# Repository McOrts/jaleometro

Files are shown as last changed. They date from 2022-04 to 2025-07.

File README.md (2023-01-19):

#   Sensor remoto y autónomo de ruido ambiental 
Este dispositivo se ha diseñado para monitorizar el ruido ambiental de forma indefinida utilizando energía solar. 

Por otra parte se van a utilizar comunicaciones de largo alcance tipo LPWAN (Low Power Wide Area Networks). En este caso será una modulación **LoRa** (Long Range) que además es muy eficientes en el consumo de energía. La tecnología LoRa y la capa de red abierta LoRaWAN son los protagonistas del despliegue del IoT.

## Material utilizado
- Hemos utilizado la [placa Heltec HTCC-AB01](https://es.aliexpress.com/item/1005001288501966.html) para la banda ISM europea de 868MHz que tiene las siguientes características:
  - Compatible con Arduino, por tanto compatible en Windows, Mac OS y Linux
  - Configurable a través de comandos AT
  - Chip CP2102 de puerto serie a USB integrado
  - Basada en ASR605x (ASR6501, ASR6502) , esos chips ya están integrados el PSoC ®  4000 serie MCU (ARM® cortex® M0 + Core) y SX1262;
  - Soporte de la especificación LoRaWAN 1.0.2
  - Diseño de energía ultra bajo, solo 3.5uA en Deep Sleep. Para este tipo de proyecto, el consumo son muy importantes y aquí tenemos es tabla que ayudará a dimensionar la batería y el panel solar:
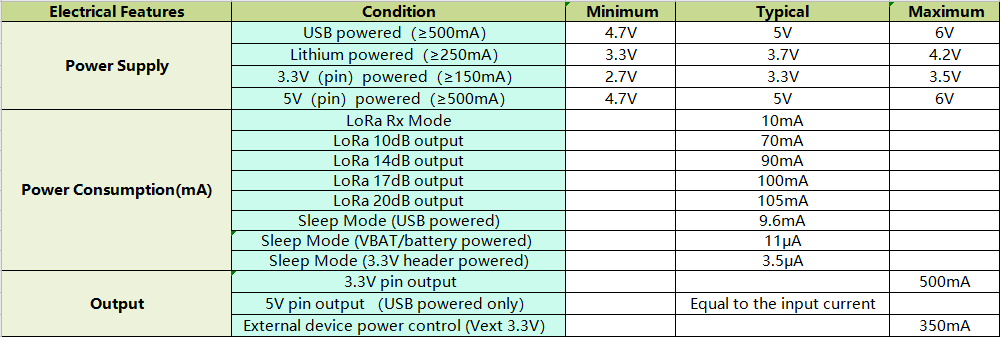
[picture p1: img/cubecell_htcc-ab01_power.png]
Consumos
   
  - Sistema de gestión de energía solar incluido, se puede conectar directamente con un panel solar de 5-7 V
  - Conector SH1.25-2 para baterías incluido, sistema de administración de batería integrado (administración de carga y descarga, protección de sobrecarga, detección de energía de la batería, conmutación automática de energía de batería / USB)
  - Interfaz micro USB con protección ESD (Electrostatic Discharge), protección contra cortocircuitos, blindaje RF y otras medidas de protección
  - Buena correspondencia de impedancia y larga distancia de comunicación
  - Certificación CE y FCC

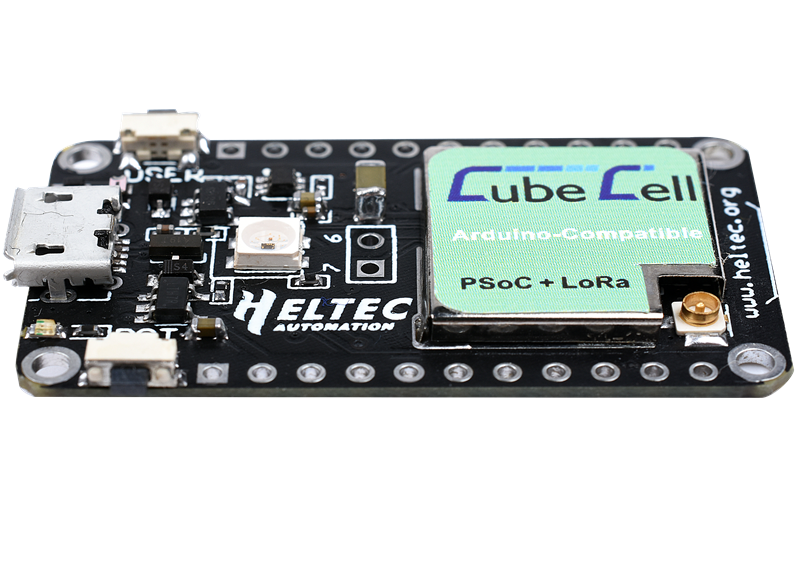
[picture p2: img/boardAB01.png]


Podremos encontrar toda la documentación de esta placa en: [Documentos y ficheros](https://resource.heltec.cn/download/CubeCell), [FAQs](https://github.com/HelTecAutomation/HeltecDocs/blob/master/en/source/cubecell/frequently_asked_questions.md) 

- [Batería de polímero de litio de 3,7V y conector JST SH1.0 de 1,0mm y dos pines](https://es.aliexpress.com/item/4000288987647.html)

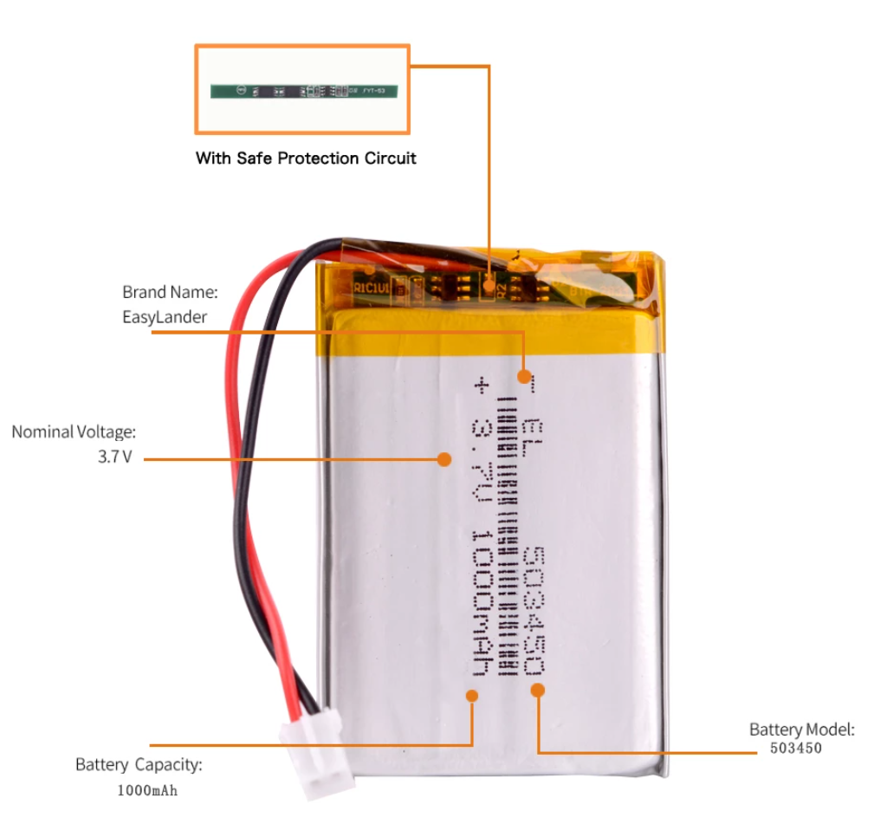
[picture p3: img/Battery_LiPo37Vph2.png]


- [Panel solar de 6V](https://es.aliexpress.com/item/4001128543657.html)

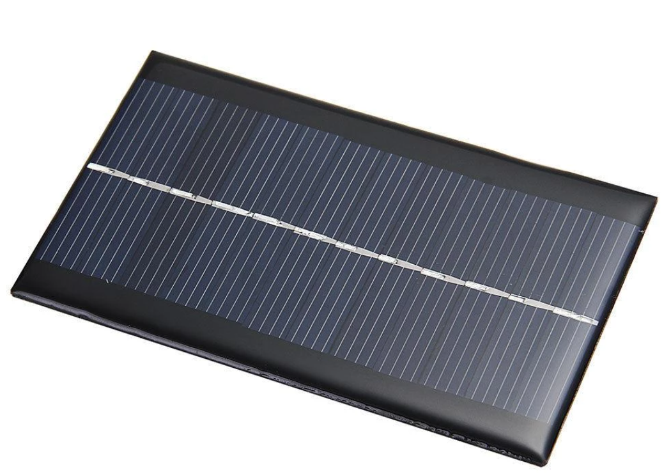
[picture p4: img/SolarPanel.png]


- [SparkFun Sound Detector](https://www.sparkfun.com/products/14262)

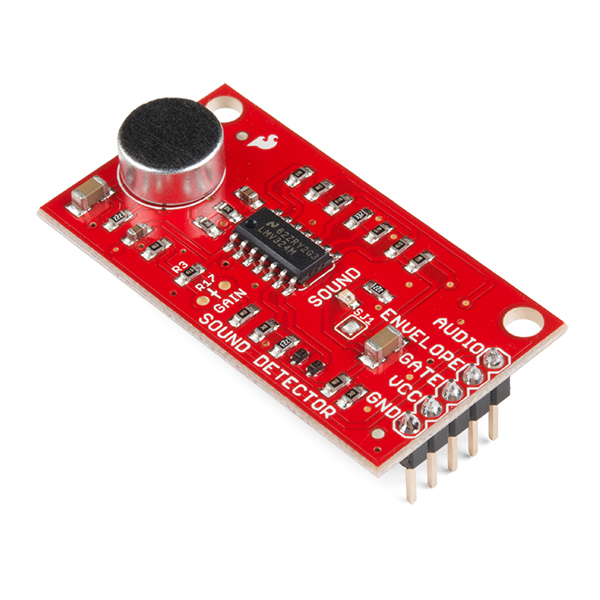
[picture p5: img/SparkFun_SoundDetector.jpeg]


- [Carcasa hermética IP66](https://es.aliexpress.com/item/33060319519.html)

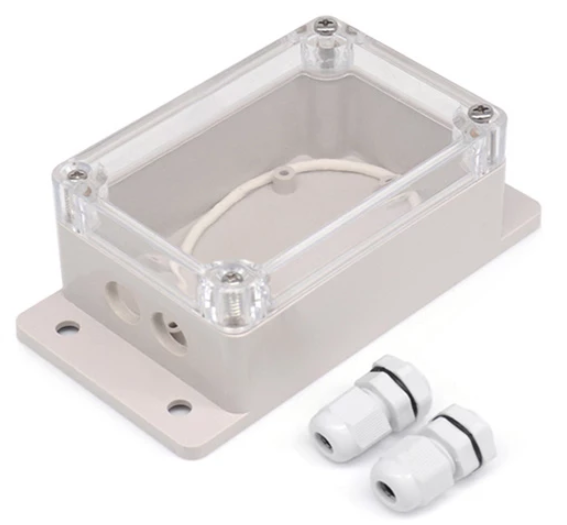
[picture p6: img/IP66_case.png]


Por otra parte también se necesitarán otros componentes no electrónicos como cables, mini-protoboard... lo que conforma este kit:

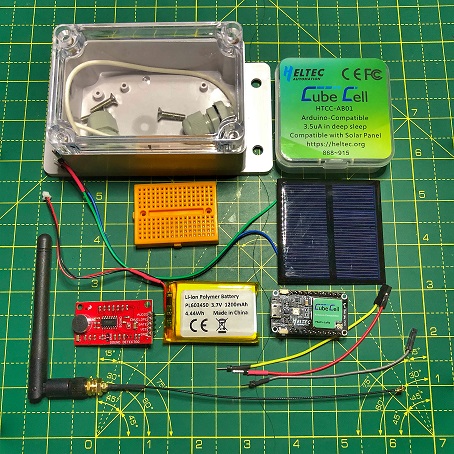
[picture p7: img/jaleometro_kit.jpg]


## Conexionado

Del microcontrolador CubeCell solo vamos a utilizar el pin 2 que corresponde al único conversor analógico/digital de la placa. Internamente es el mismo que utiliza para ver el estado de carga de la batería. Por lo que perderemos esta función.  

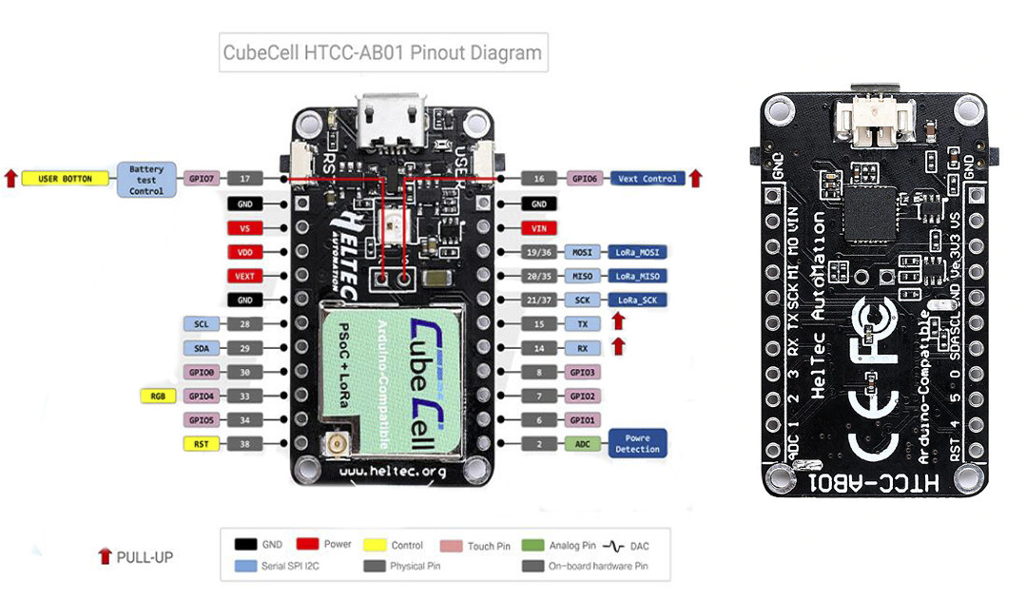
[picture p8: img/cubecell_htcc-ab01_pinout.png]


Otro detalle a tener en cuenta respecto a la alimentación del sensor de sonido, es que aunque sería recomendable utilizar una tensión de 5V que suministraría la placa por el pin VIN. Este solo tiene tensión cuando se alimenta por USB. Por lo que tendremos que utilizar el pin VDD que suministra 3.3 en la configuración de batería y son suficientes para que el sensor funciones correctamente.

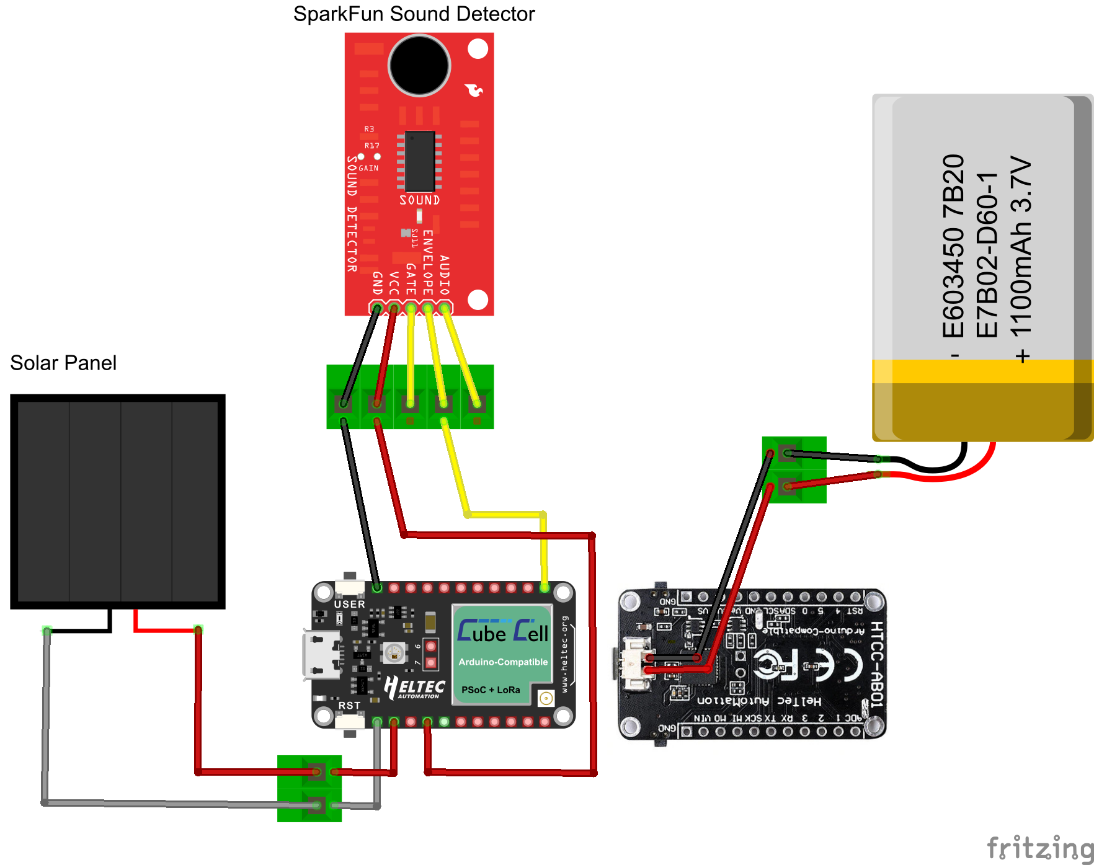
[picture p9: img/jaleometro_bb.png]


### Tuneo del sensor de Sparkfun
Las pruebas realizadas con la v0 revelaron falta de sensibilidad. El sensor permite esta ajuste por hardware soldando una resistencia en este punto:

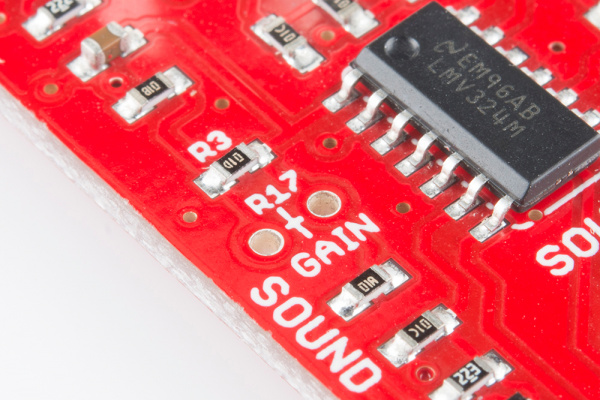
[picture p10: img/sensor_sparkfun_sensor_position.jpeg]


Los valores posibles están en esta tabla:



Y finalmente en nuestro caso elegimos la de 1M para obtener una ganancia de 60 dB:

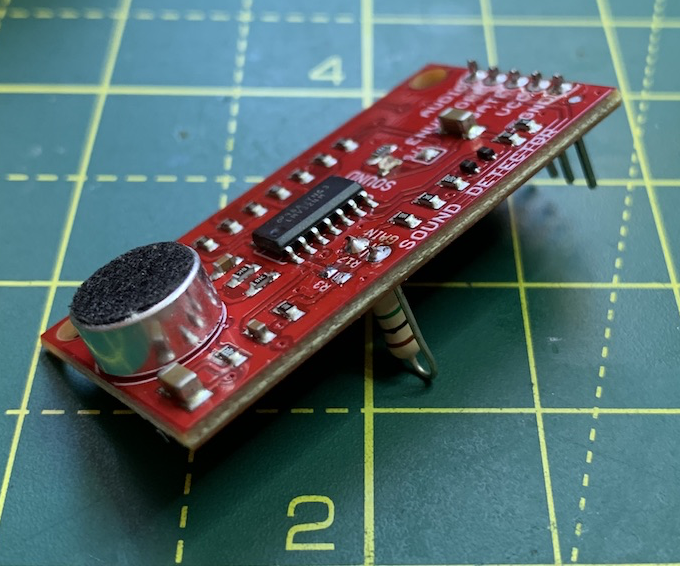
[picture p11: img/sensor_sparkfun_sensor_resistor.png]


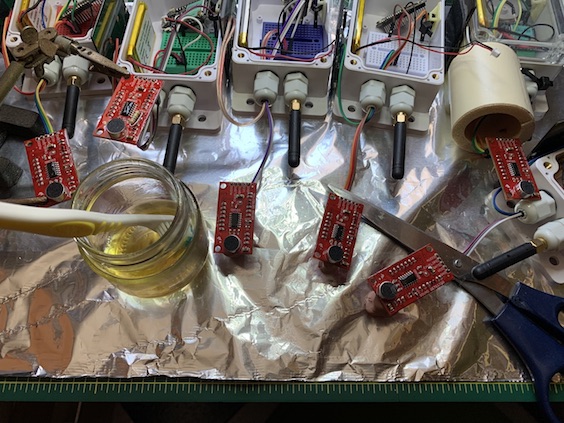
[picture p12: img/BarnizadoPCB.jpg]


Debido a que el sensor estará fuera de la caja estanca. Aunque protegido por material plástico. Requiere de una protección especial a fin de retardar todo lo posible la oxidación de sus componentes. Hay muchas soluciones, pero hemos elegido la más artesanal usando resina colofonia disuelta al 40% en alcohol isopropílico. La solución se puede aplicar con pincel y el tiempo de secado es de unas 24 horas.

## Configuración IDE Arduino
Lo para poder programar adecuadamente el dispositivo tendremos que configurar el entorno de programación de Arduino con las configuraciones de hardware y librerías de esta placa.
1. Añadir la URL https://github.com/HelTecAutomation/CubeCell-Arduino/releases/download/V1.5.0/package_CubeCell_index.json a Preferences->Settings->Additional boards:
2. Añadir la librería de CayenneLPP. **Importante: versión 1.1.0**:

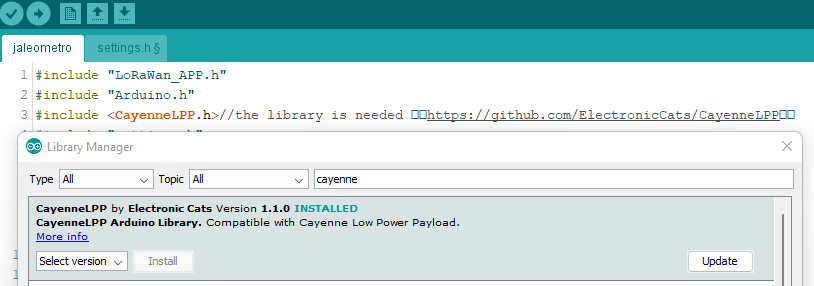
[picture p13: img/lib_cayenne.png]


3. Si aparece un aviso de instalar otras librerias con dependencias. Seleccionar opción de instalar todas:

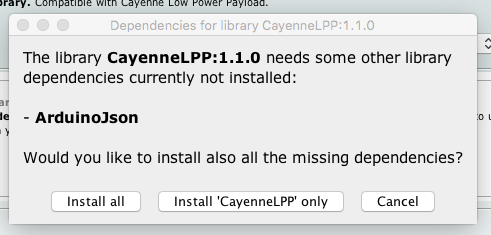
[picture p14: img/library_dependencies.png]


4. Seleccionar la tarjeta CubeCell HTCC-AB01 y configurar todos sus parámetros así:

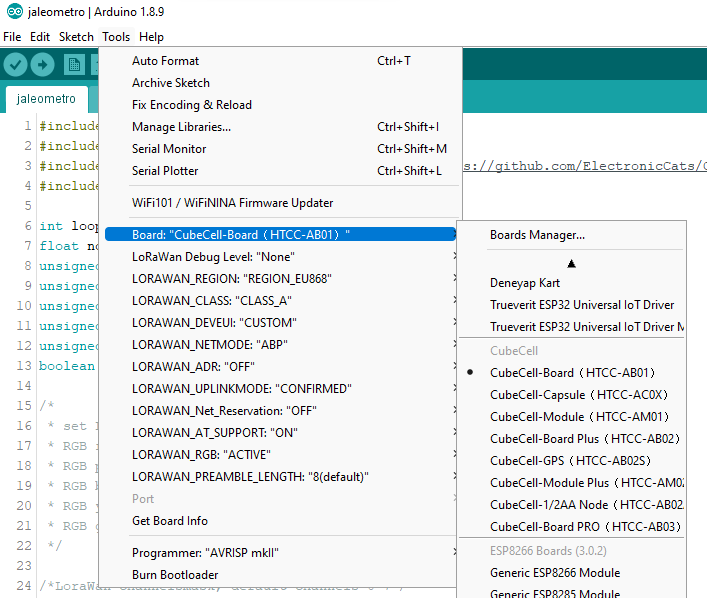
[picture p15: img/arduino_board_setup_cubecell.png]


### Subir el sketch de Arduino
Con el cable conectado seleccionamos el puerto USB que nuestro ordenador haya asignado. Una vez compilado y cargado en el dispositivo. Abrimos el monitor serie para comprobar que log de actividad del programa es correcto.

## Configuración del sensor en la nube (TTN)

Vamos a utilizar los servicios de The Things Network que es un servicio en la nube al que están conectados los _gateway_ libres de la las Comunidades TTN. 
La ruta de la información es la siguiente:
1. El sensor (_nodo_) transmite por radio con modulación LoRa el trama de datos que recibe el _gateway_
2. Este _gateway_ está conectado a internet para retransmitir la trama, hora como paquete de datos.
3. Los servidores de TTN decodifican el mensaje y ofrecen diferentes integraciones y _endpoints_ para que nuestras aplicaciones utilicen la información leída por los sensores.

Hay muchas variantes para implementar este enrutamiento. Para este se ha elegido estas configuraciones:
- Dispositivo es del tipo ABP (Activation-by-personalisation) lo que significa que se identificará en la red con un _DevAddr_ y una _Session key_ preconfigurada. Para ello tenemos que completar el registro de una aplicación y un dispositivo. 
- Publicación del paquete de-codificado en una cola MQTT a la que nuestra aplicación está subscrita.

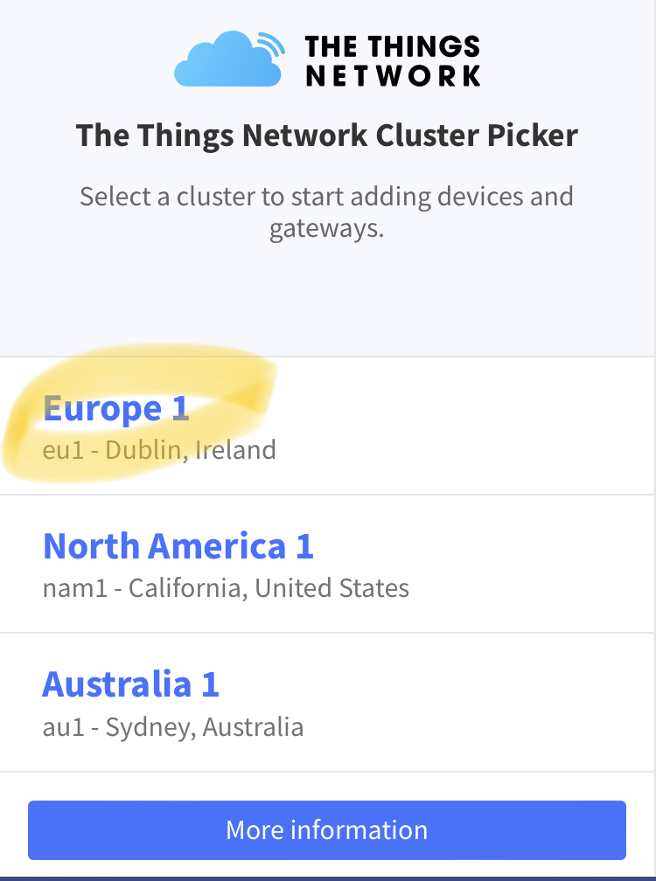
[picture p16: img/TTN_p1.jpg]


Estos son los pasos a seguir empezando por acceder a la aplicación _back-end_ de TTN en esta URL: https://console.cloud.thethings.network/ en la que seleccionaremos nuestra región y luego nos loguearemos con nuestro usuario registrado.

<br>
<br>
<br>
<br>
<br>
<br>
<br>

### Registro de la aplicación
En TTN los dispositivos (_devices_) iguales, se agrupan en una aplicación desde la cual serán registrados. por lo tanto, primero hay que añadir una aplicación:

En el formulario de alta de aplicación rellenaremos estos campos: 
- Para el _Application ID_, elige un identificador único, en minúsculas, puedes usar caracteres alfanuméricos peor no guiones ´-´ consecutivos.
- Para  _Description_, elige la descripción que prefieras.
- No hace falta poner nada en _Application EUI_ 
- Presiona _Create application_ para finalizar

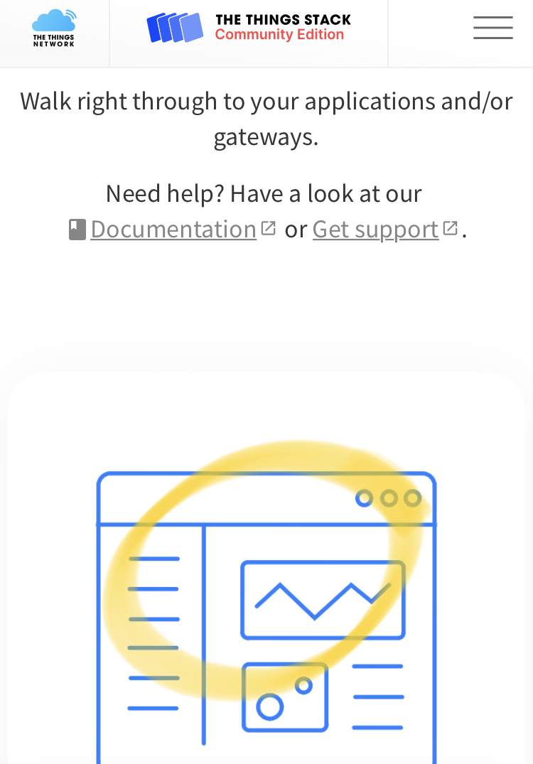
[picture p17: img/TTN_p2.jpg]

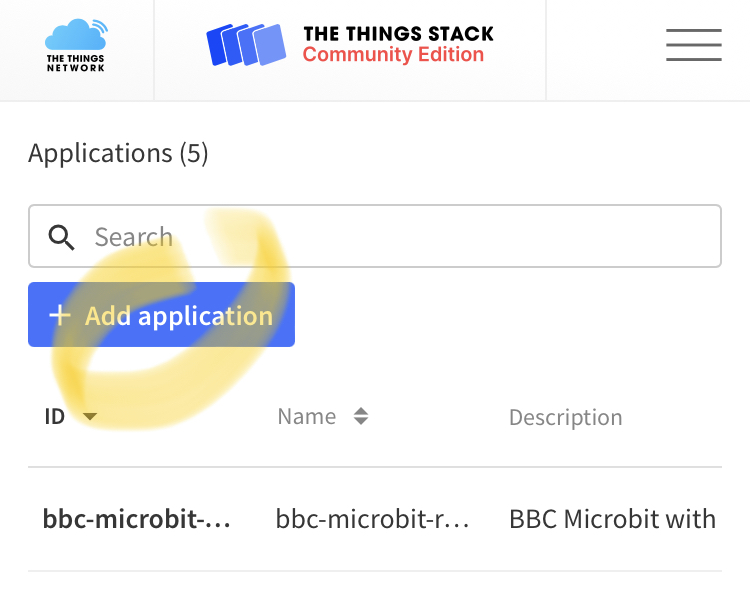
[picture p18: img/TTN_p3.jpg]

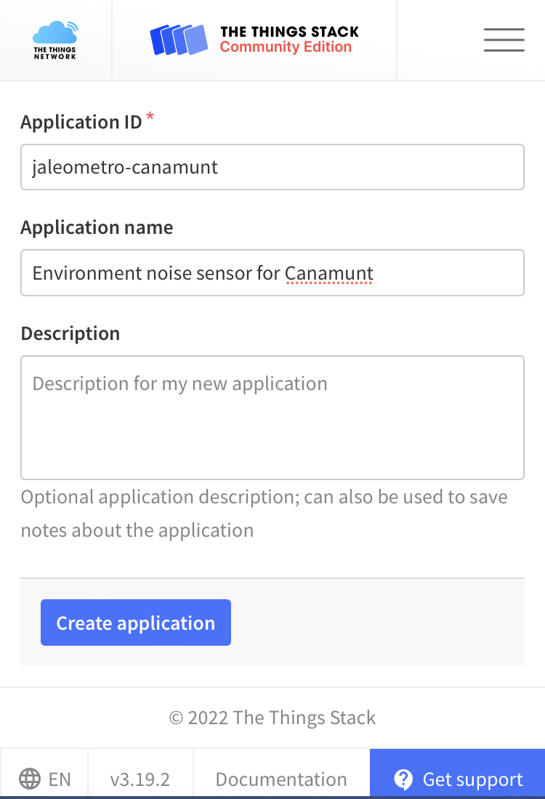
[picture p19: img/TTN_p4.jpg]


<br>
<br>
<br>
<br>
<br>
<br>
<br>
<br>

Aparecerá ahora la página con la nueva aplicación añadida donde encontrarás un botón de _+ Add end device_ necesario para crear los dispositivos asociados. 

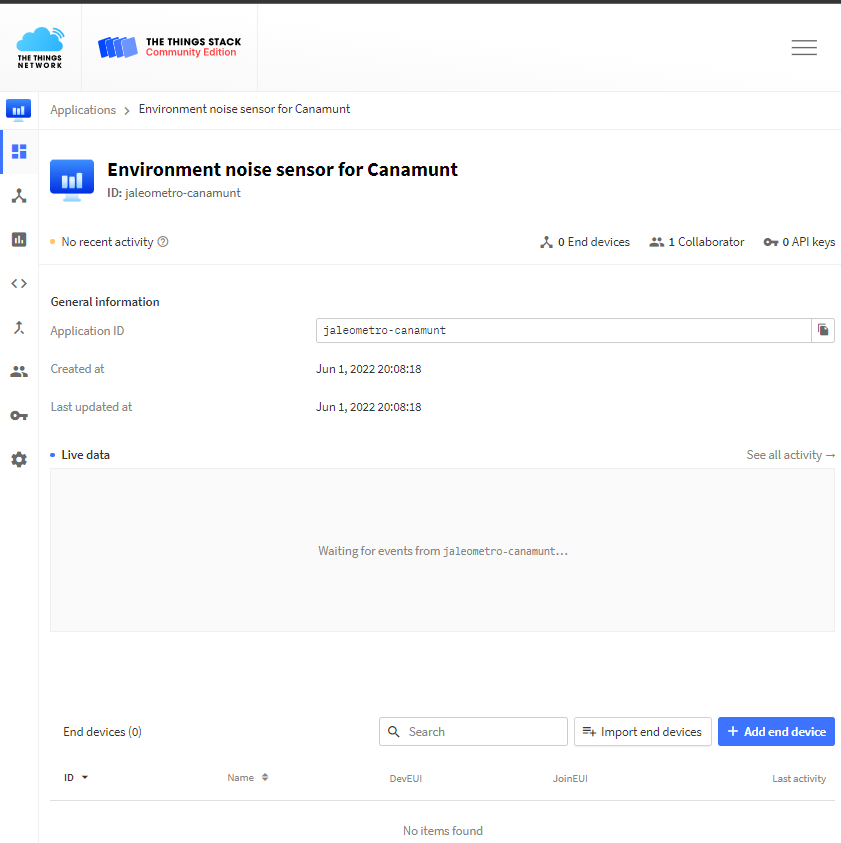
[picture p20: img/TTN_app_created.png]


### Registro del dispositivo
En TTN un dispositivo (devide) representa la configuración de lo que también llama nodo (node) que a fin de cuentas es nuestro sensor. 
Al acceder al formulario de registro nos quedamos en la pestaña de _From The LoRaWAN Device Repository_ ya que estamos usando un microcontrolador conocido.
Ahora tenemos que seleccionar el tipo, modelo y marca de nuestro sensor tal y como aparece en la captura inferior. 
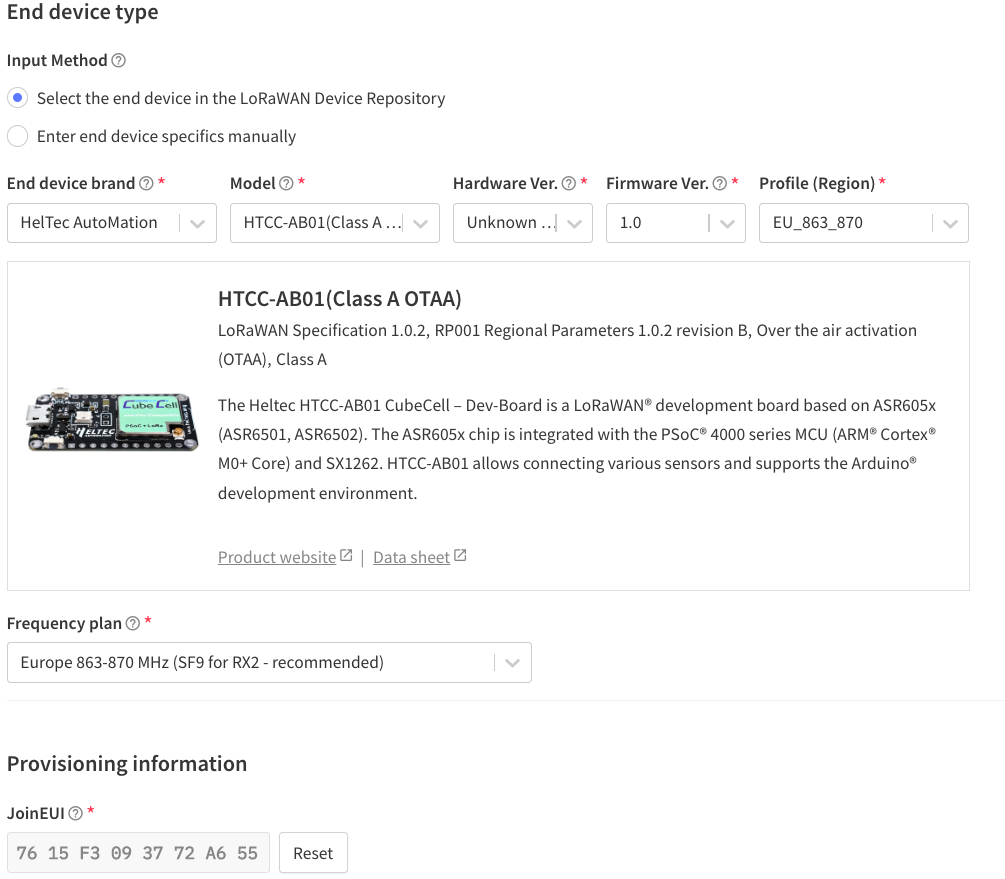
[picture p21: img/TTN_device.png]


El la casilla inferior vemos que pide una clave de JoinEUI que normalmente nos la daría el fabricante. Pero en nuestro caso utilizaremos una sencilla aplicación web para generarla:  https://descartes.co.uk/CreateEUIKey.html
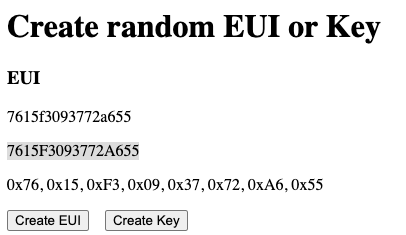
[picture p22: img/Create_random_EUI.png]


Lo siguiente será generar las _DevEUI_ y _AppKey_ pulsando los correspondientes iconos de la derecha para que se genere automáticamente.
Finalmente queda rellenar el _Device ID_ que será el nombre único de este nodo.

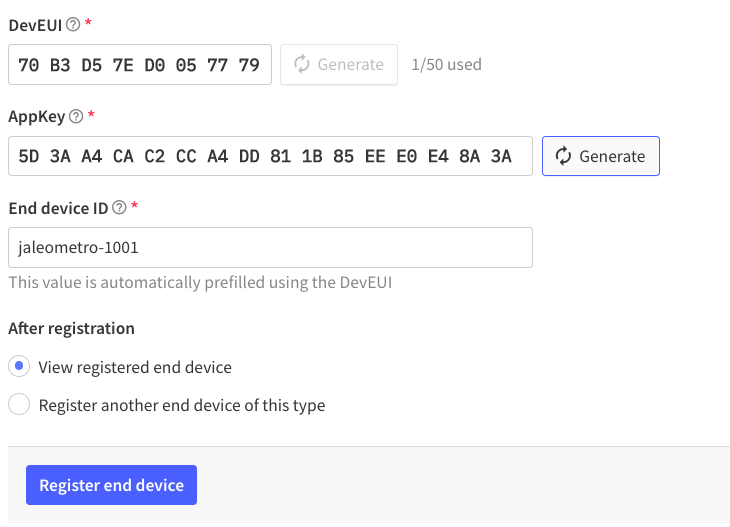
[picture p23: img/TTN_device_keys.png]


Finalmente pulsaremos _Register en device_ para que, seguidamente aparezca la pantalla con la configuración de nuestro nuevo nodo.Aquí podremos ver los datos de configuración y parámetros que necesitamos por ser un dispositivo de tipo ABP. Y que tendremos que pasar al fichero de configuración settings.h que se cargará en el _sketch_ del IDE de Arduino.

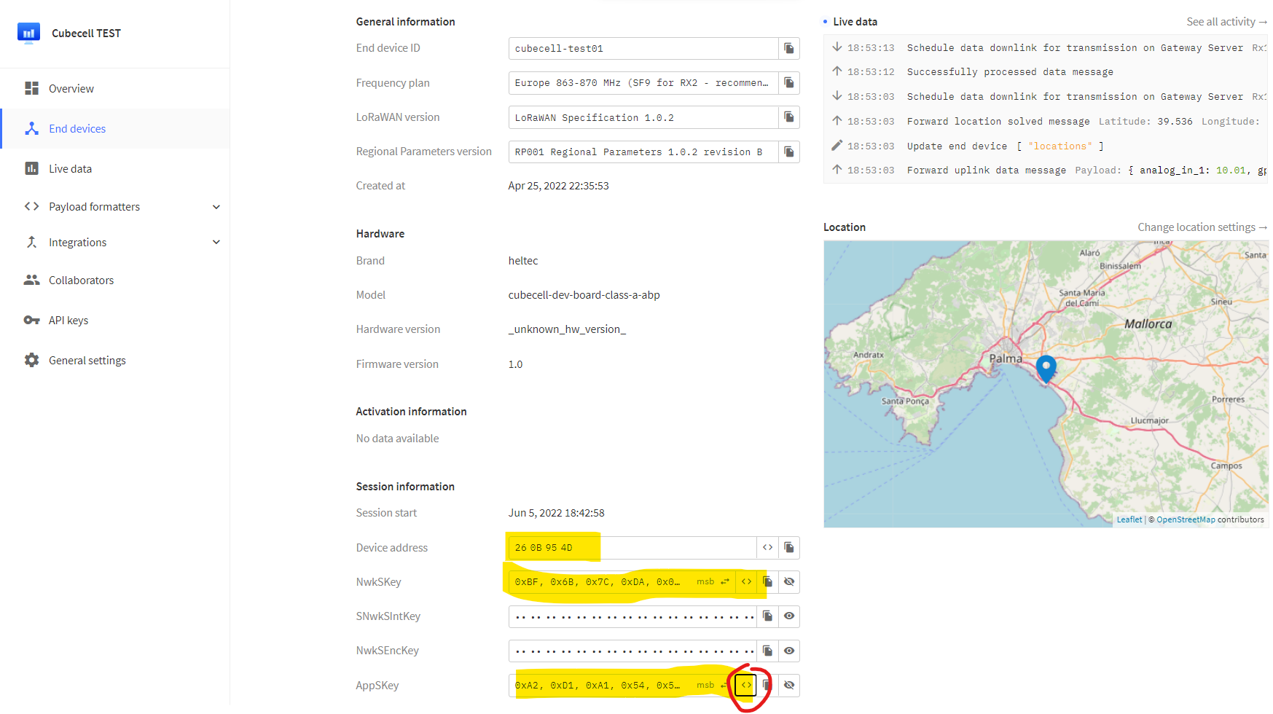
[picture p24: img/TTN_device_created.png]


Para poder copiar las _keys_ en el formato "array" que se requiere en el fichero de configuración: "settings.h" 
Nota: hay que pulsar el icono <> de "_toggle array formating_" para tener el formato adecuado para este fichero.

```cpp
// LoRaWAN Configuration

/* OTAA para*/
static uint8_t devEui[] = {  };
static uint8_t appEui[] = {  };
static uint8_t appKey[] = {  };

uint16_t userChannelsMask[6]={ 0x00FF,0x0000,0x0000,0x0000,0x0000,0x0000 };
static DeviceClass_t lorawanClass = LORAWAN_CLASS;

// Devise location
const float latitude = 39.573;
const float longitude = 2.732;
const int alt = 20;

// Other params
float SensorId= 10.01;// Sensor  identifcator number 
const int DutyCycle = 600000; // Transmision and reading period
const int Sleep4NoNoise = 300000; // Sleep period when low noise 
const int LowNoiseLevel = 180; // Limit for low noise mode
```

### Formato de la trama

Desde el menú vertical izquierdo accederemos al _Payload Formatters_ y la opción Uplink para definir cómo decodificar la trama de datos de nuestro mensaje LoRa que hemos establecido en el firmware. En nuestro caso hemos usado la librería CayenneLPP y esto es lo que aquí tenemos de seleccionar como tipo:

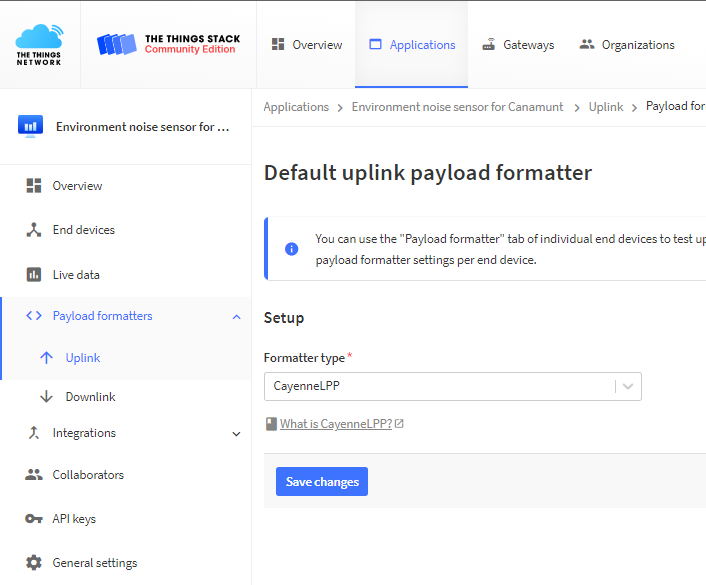
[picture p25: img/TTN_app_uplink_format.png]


De esta manera el mensaje MQTT que vamos a utilizar para leer los valores del sensor; será generado por backend de TTN en una estructura JSON perfectamente formateada:

```json
{
 "uplink_message":{
      "f_port":2,
      "f_cnt":539,
      "frm_payload":"AQID6QFlAE8CZQDDAogGCGAAaiwAC7g=",
      "decoded_payload":{
         "analog_in_1":10.02,
         "gps_2":{
            "altitude":30,
            "latitude":39.936,
            "longitude":3.718
         },
         "luminosity_1":79,
         "luminosity_2":195
      }
}
```
### Integración MQTT
Por último necesitaremos las credenciales de acceso al broker MQTT que TTN nos ofrece como una opción de integración para poder suscribirnos a topic desde nuestra aplicación:

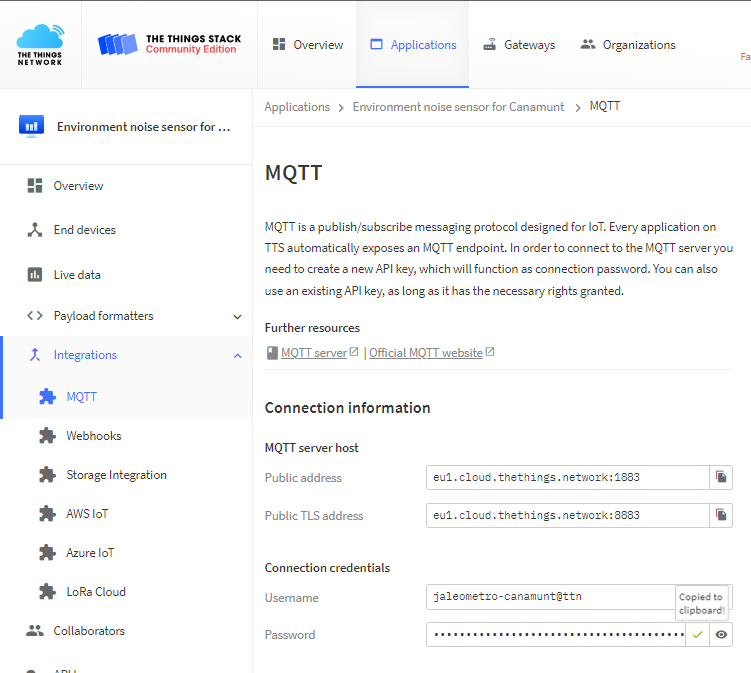
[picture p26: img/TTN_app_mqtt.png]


**IMPORTANTE**: copia el password ahora porque una vez cerrada esta ventana. No tendrás opción a consultarlo.

## Análisis de la señal
Cuando hablamos de sonido o de ruido, la magnitud que se utiliza con mayor frecuencia son los dBA y la medida estandarizada para calidad ambiental es la LAeq (Equivalent Continuous Sound Pressure Level). En nuestro caso será para el tiempo dado de 10 minutos.
Calcular este indice requiere de varias transformaciones, calibrados y cálculos que se detallan a continuación:

1. (A) Partimos que el sensor de sonido _SparkFun Sound Detector_ nos da una medida analógica con un rango de 0 a 4500. Puede dar valores superiores pero aplicamos un filtro software de banda alta para eliminar los _outlier_. Si embargo esta medida analógica no es el valor instantáneo del sonido o presión sonora. Si no la envolvente de 1 segundo de muestreo calculada por el circuito del sensor. Línea verde del gráfico:
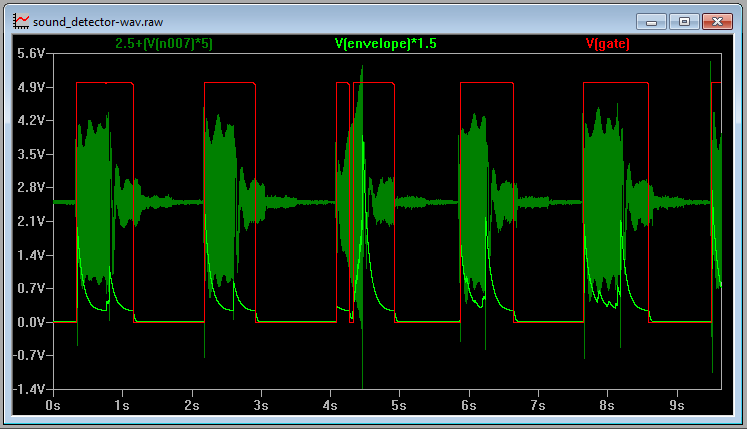
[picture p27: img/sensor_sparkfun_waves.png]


Este gráfico muestra los voltajes de salida a lo largo del tiempo.
- El trazo verde oscuro es la salida de audio del detector de sonido. El voltaje de audio directamente desde el micrófono se encuentra en esta salida.
- El trazo verde claro es la envolvente. Este voltaje analógico rastrea la amplitud del sonido. Se puede observar que el tercer pulso se vuelve notablemente más fuerte a medida que avanza.
- Finalmente, la línea roja es la salida de la puerta. Esta salida es baja cuando las condiciones son tranquilas y aumenta cuando se detecta sonido.
1. (B) Y tenemos que determinar el valor base que corresponda con la medida en silencio.
2. Calculamos el ruido medio del periodo de ciclo de transmisión que es de 10 minutos. 



Donde:
Leq = nivel de presión sonora continuo equivalente en dB
p0 = nivel de presión de referencia (típicamente 20 µPa)
pA = presión sonora adquirida
t1 = tiempo de inicio de la medición
t2 = tiempo de finalización de la medición
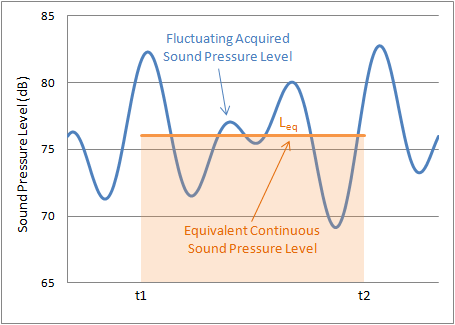
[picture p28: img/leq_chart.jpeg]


3. Finalmente para obtener el LAeq basándonos en la media y no al Leq anterior que sería lo correcto. Aplicamos la fórmula que nos dará una magnitud en decibelios:
> **LAeq = Calibración * 20 * log10 ( Ruido Medio / Ruido Base )**

## Gráficas y alarmas en Node-RED
Partimos de una instancia Node-RED con nodo para mostrar un interface de usuario que se llama _dashboard_. Lo que se puede hacer desde la opción _Manage Palette_ de la aplicación de administración.

Se ha construido un sencillo flujo para representar unas gráficas y poder establecer un umbral de alerta para enviar un mensaje a IFTTT



El cual genera el siguiente dashboard:

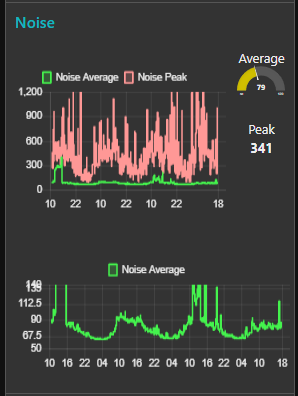
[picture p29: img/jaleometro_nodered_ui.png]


En el flujo de Node-RED se tratan y muestran gráficamente los mensajes MQTT leidos. El _payload_ contiene el json con los valores de:
- Ruido medio en "luminosity_1"
- Ruido pico en "luminosity_2"
- Id de sensor en "analog_in_1"
- Coordenadas geográficas en "gps_2"

Para importar el flujo deberemos acceder a la aplicación Node-RED que tenemos arrancada dónde encontraremos la opción de importar pulsando el botón de menú tipo hamburguesa. Lo más fácil es copiar al portapapeles de equipo el contenido del fichero jaleometro_nodered_ui_mqtt y pegarlo en la pantalla:

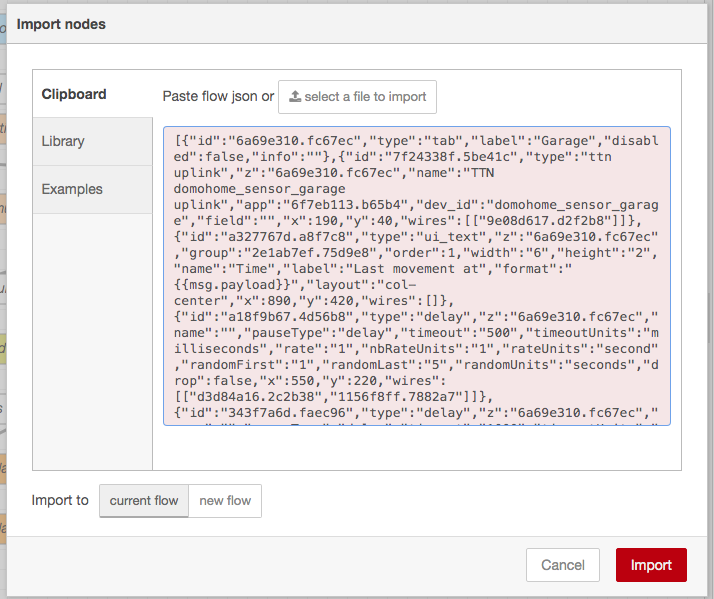
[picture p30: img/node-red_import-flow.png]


Tras pulsar el botón de ¨import¨ tendrás la vista de los nodos y los flujos. Pero hay tres de ellos que no están correctamente configurados.

### Configuración cliente MQTT
Encontrarás todo configurado excepto las credenciales de acceso. Para utilizar las que has obtenido en los pasos anteriores. Solo tienes que ir a las propiedades del nodo MQTT, editar el _Server_ y acceder a la pestaña _Security_:

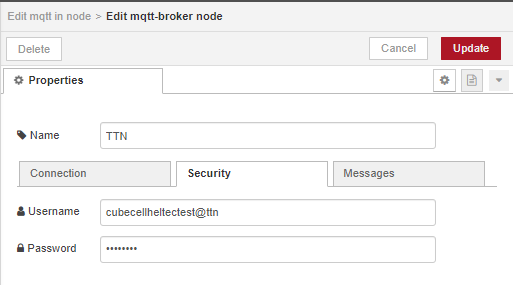
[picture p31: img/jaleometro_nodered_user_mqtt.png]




### Configurar integración con IFTTT
La integración con IFTTT (If This Then That) está montada con una sencilla llamada a su _endpoint_ REST utilizando en nodo tipo _http request_ con el siguiente formato. 
<br>
```
https://maker.ifttt.com/trigger/domohome_garage_intruder/with/key/???????????
```
<br>
Donde sustituiremos las interrogantes por la Key que encontramos en esta configuración del componente Maker _Webhooks_ en IFTTT. Que configuraremos para recibir el evento disparar los avisos nativos en nuestra móvil a fin de tener notificación de la alarma.



## Agradecimientos
- A Christoph Hafner y Javier Maura cuyo proyecto Moix me ha servido de inspiración https://github.com/Makespace-Mallorca/moix
- A mi ex-compañero Alexandre Coll por sus buenos consejos de cómo medir el ruido https://www.linkedin.com/in/alexandre-coll-molina/
- A Sparkfun por su buena documentación: https://learn.sparkfun.com/tutorials/sik-experiment-guide-for-the-arduino-101genuino-101-board-spanish/experimento-15-usar-la-placa-de-detector-de-sonido

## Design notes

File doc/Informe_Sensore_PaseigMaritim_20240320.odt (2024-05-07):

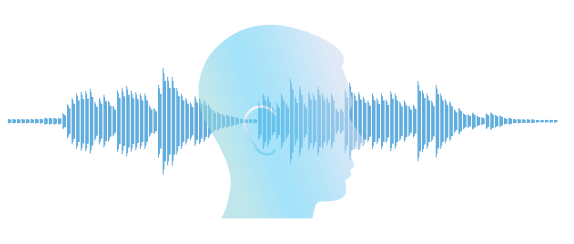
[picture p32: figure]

INFORME DE RUIDO

Sensor Zona Passeig Marítim

Abril 2024

Red de sensores ambientales desarrollados, construidos y

mantenidos por la Asociación de Makers de Mallorca

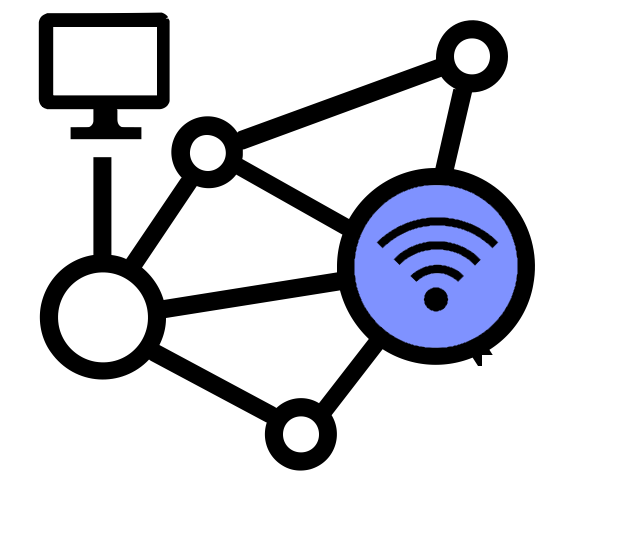
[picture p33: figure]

Informe de ruido | IoT Foundations
Sensores Paseig Maritim | Abril 2024

Índice

1. Introducción

2. Informe ejecutivo

3. Análisis de las emisiones acústicas

Informe de ruido | IoT Foundations
Sensores Paseig Maritim | Abril 2024

1. Introducción

El presente documento tiene por objeto el análisis comparativo de las lecturas de los sensores del sábado día 20 de abril de 2024

Los sensores de ruido ambiental utilizados están diseñados y construidos bajo los estándares de hardware y software abierto. Por lo que la documentación técnica es de acceso libre y se puede consultar en: https://github.com/McOrts/jaleometro

Informe de ruido | IoT Foundations
Sensores Paseig Maritim | Abril 2024

2. Informe ejecutivo

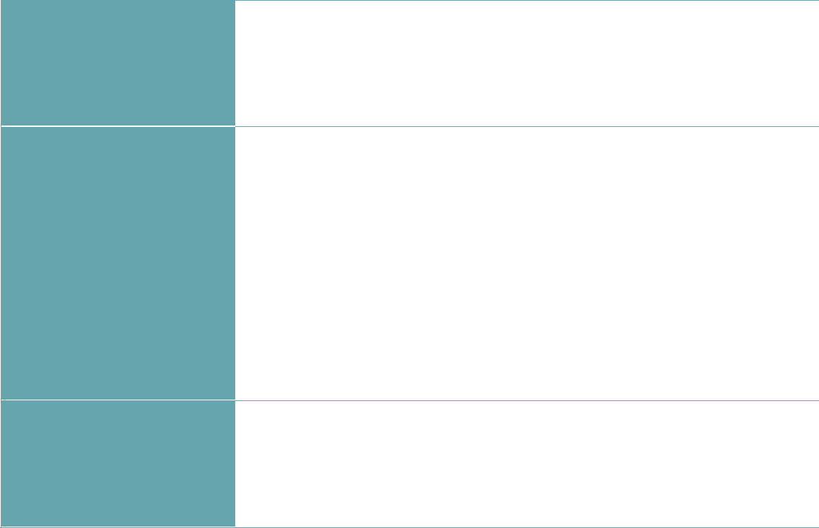
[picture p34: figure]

Disponibilidad

Análisis de las mediciones acústicas

Incidencias

Los sonómetros objeto de este estudio han estado operativos en un 100% en el periodo de estudio de este informe:

- Desde las 15:00 del 20 abril de 2024
- A las 15:00 del 21 abril de 2024

Se han detectado unos eventos de ruido alto inusuales en el mismo periodo de tiempo de otros fines de semana.

Comparativamente con el análisis respecto a otros 20 sensores de ruido de la ciudad de Palma de Mallorca. Muestra unos indicadores de mediciones, alarmas y alertas que sitúan a esta localización dentro de las dos más ruidosas.

Localizaciones

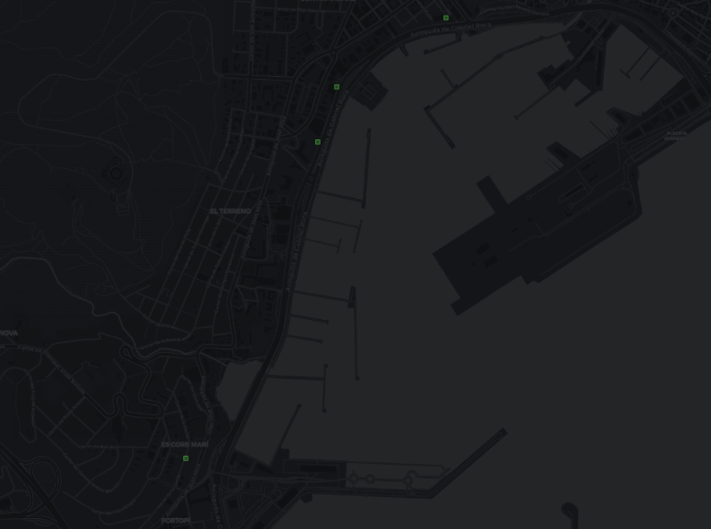
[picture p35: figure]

Informe de ruido | IoT Foundations

Informe de ruido | IoT Foundations
Sensores Paseig Maritim | Abril 2024

3. Análisis de las emisiones acústicas

Se muestran las mediciones principales del ruido medio calculado en base al Laeq, indicador utilizado en la normativas municipales e internacionales.

Se muestra con una línea en amarillo, límite de los 55 dBa establecido para el horario nocturno:

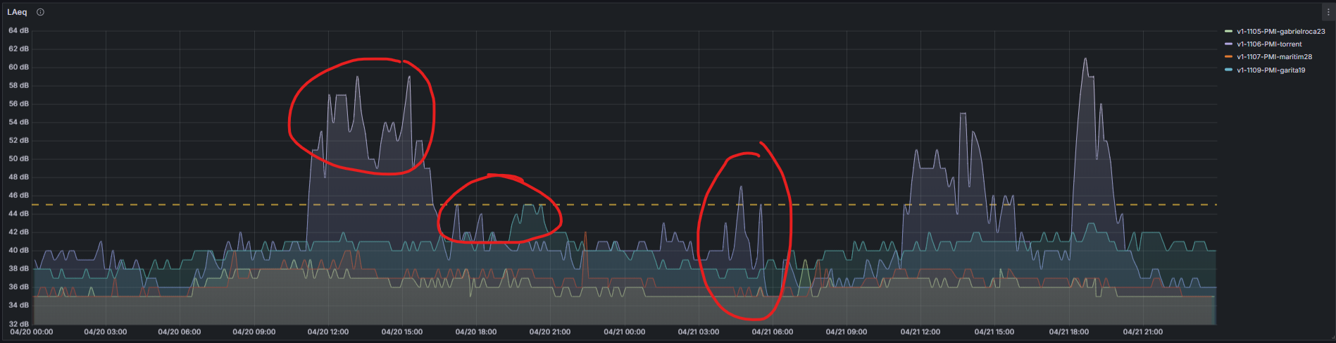
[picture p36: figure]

Observaciones:

- En torno a las 5 am se detecta un nivel medio de ruido nocturno por encima del límite establecido en las Ordenanzas Municipales en el sensor de la Plaza Torrent
- El sensor de la plaza de Torrent también un alto nivel de ruido diurno a partir del mediodía que es relevado por las más altas mediciones del situado en Gabriel Roca 23.
  - Este evento es excepcional respecto a las mediciones del otros fines de semana como el anterior:

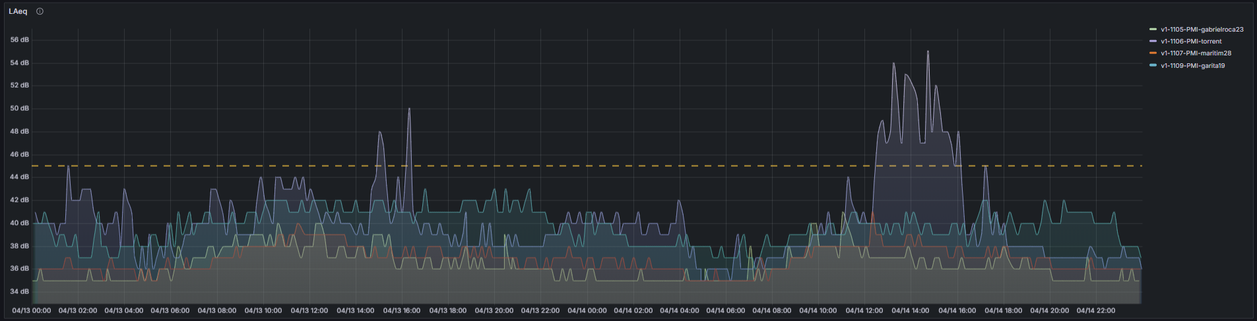
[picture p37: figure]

Respecto a la medición de ruido máximo detectado en cada periodo de muestra de 10 minutos, esta es la gráfica con las líneas límites nocturnas y diurnas:

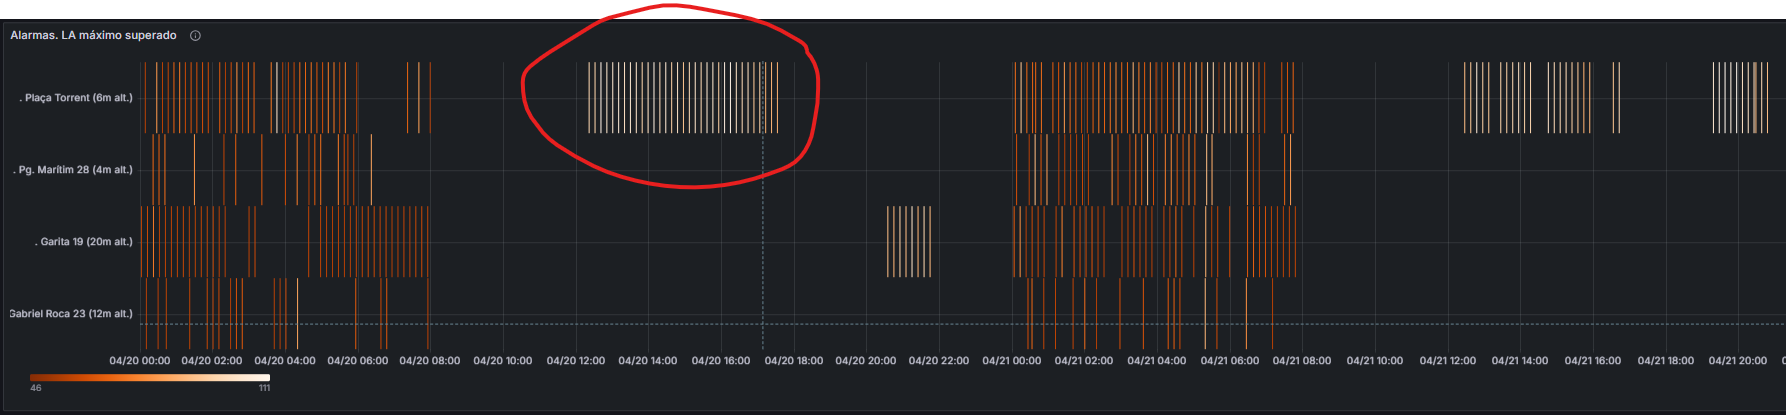
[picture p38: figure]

Destaca una concentración de alarmas en torno al sensor y el horario de los máximos de ruido medio Laeq vistos anteriormente. Y que también son excepcionales respecto a otros fines de semana:

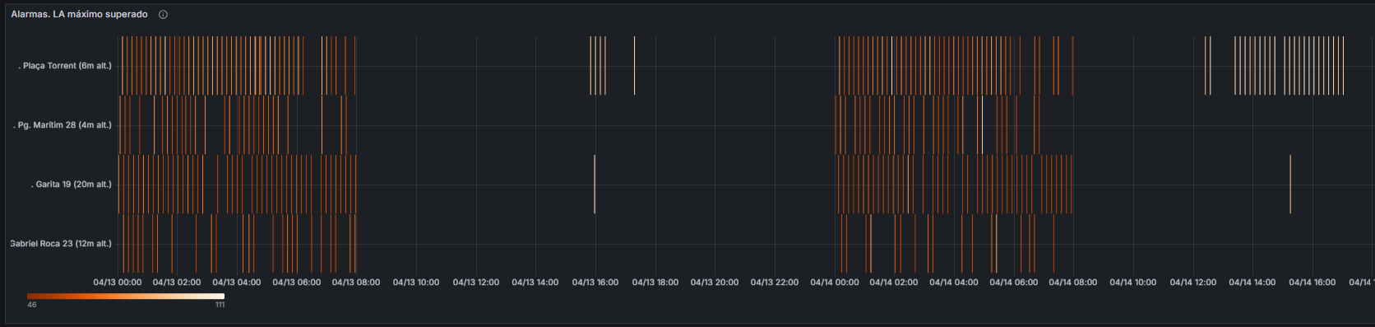
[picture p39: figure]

Mapa comparativo

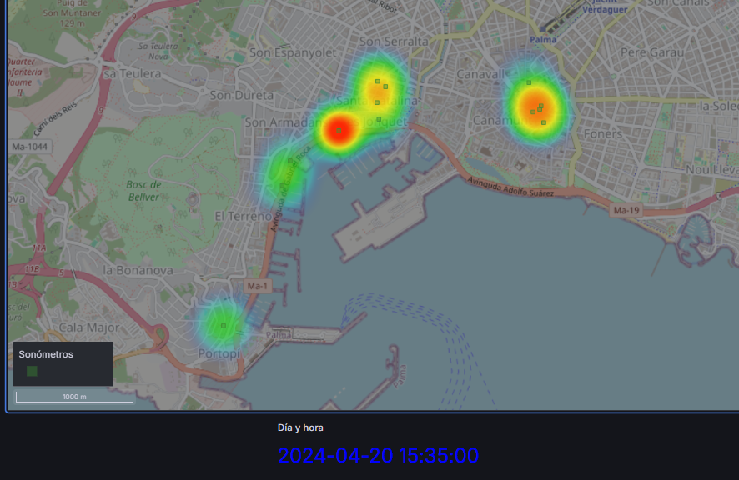
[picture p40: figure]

En el mapa de calor comparativo con los sensores de otras zonas de Palma de Mallorca. Se puede observar claramente que las zonas de máxima intensidad de ruido están en torno a la Plaza Torrent:

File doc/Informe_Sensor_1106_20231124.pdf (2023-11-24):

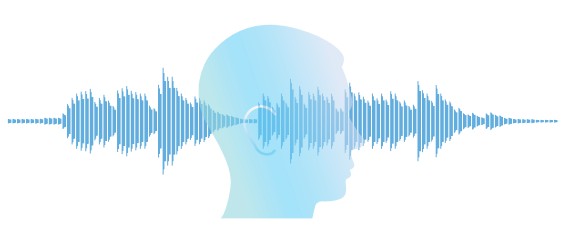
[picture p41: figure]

# INFORME DE RUIDO

# Sensor 1106 | Plaça Torrent (6m altura) |Zona Passeig Marítim

# NOVIEMBRE 2023

Red de sensores ambientales desarrollados, construidos y mantenidos por la Asociación de Makers de Mallorca

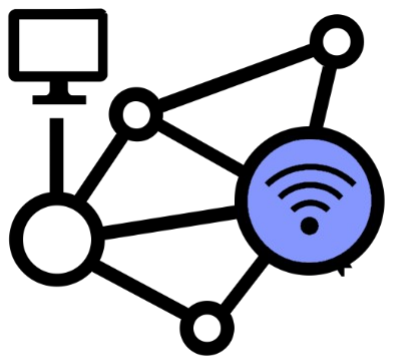
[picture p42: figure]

Informe de ruido | IoT Foundations
Sensor 1106 | 2023-11-24

# Índice

## 1. Introducción | 2. Informe ejecutivo | 3. M etodología, cálculos y umbrales | 4. Análisis de las emisiones acústicas |

## 1. Introducción

El presente documento tiene por objeto el análisis histórico de:

- Mediciones acústicas de los últimos 3 meses, con la discriminación del ruido atribuible a la actividad de locales o ocio, tráfico rodado pesado y obras de la vía pública.
- Comparativa con sensores de referencia.

Los sensores de ruido ambiental utilizados están diseñados y construidos bajo los estándares de hardware y software abierto. Por lo que la documentación técnica es de acceso libre y se puede consultar en: https://github.com/McOrts/jaleometro

## 2. Informe ejecutivo

### Disponibilidad

Análisis de las
mediciones
acústicas

### Incidencias

El dispositivo objeto de este estudio ha estado operativo en un 87,74% en el periodo de estudio de este informe:

### - Desde las 20:00 del 25 agosto de 2023 - A las 17:00 del 24 noviembre de 2023

Hay un claro patrón de ruido máximo puntual excedido de los límites nocturnos en torno a la media noche de los sábados y los domingos. Que no está justificado con el ruido procedente del tráfico de camiones nocturno ya este se produce todas las noches y en el resto de la semana no hay un patrón de ruido excedido.

Comparativamente con el análisis respecto a otros 12 sensores de sonido de la ciudad de Palma de Mallorca. Muestra unos indicadores de mediciones, alarmas y alertas que sitúan a esta localización dentro de las dos más ruidosas.

A mediados del mes de octubre se activó el ajuste de compensación de ruido por viento. El sensor está expuesto a vientos dirección S y SE.

### Horarios de las fuentes de ruido próximas

Este sensor se ve afectado de tres tipos de fuentes de ruido: locales de ocio nocturno, obras en vía pública y tráfico rodado pesado.

A continuación, se detallan los horarios observados de estas actividades:
Nombre | Días | Horario
Local Shamrock | Toda la semana | De 18h a 6h
Toda la semana Local Three Lions | De 20h a 6h
Obras públicas | De lunes a viernes | De 8h a 16h
Tráfico camiones | Toda la semana | De 4h a 7h

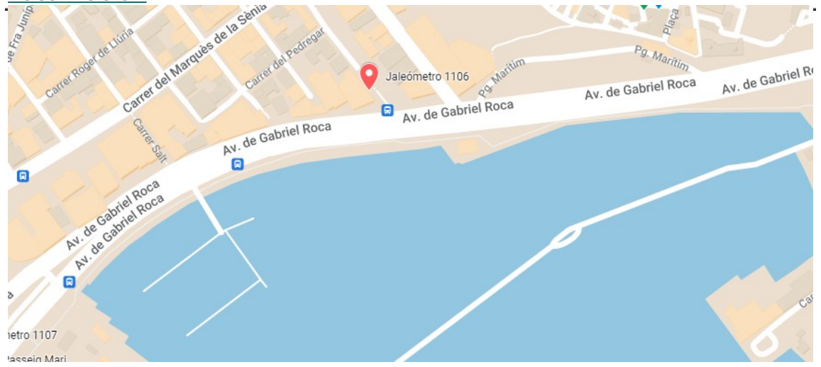
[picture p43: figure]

### Localización

## 3. Metodología, cálculos y umbrales

El Cuando hablamos de sonido o de ruido, la magnitud que se utiliza con mayor frecuencia son los dBA y la medida estandarizada para calidad ambiental es la LAeq (Equivalent Continuous Sound Pressure Level). En nuestro caso será para el tiempo dado de 10 minutos. Calcular este indice requiere de varias transformaciones, calibrados y cálculos que se detallan a continuación:

(A) Partimos que el sensor de sonido SparkFun Sound Detector nos da una medida analógica con un rango de 0 a 4500. Puede dar valores superiores pero aplicamos un filtro software de banda alta para eliminar los outlier. Si embargo esta medida analógica no es el valor instantáneo del sonido o presión sonora. Si no la envolvente de 1 segundo de muestreo calculada por el circuito del sensor. Línea verde del gráfico:

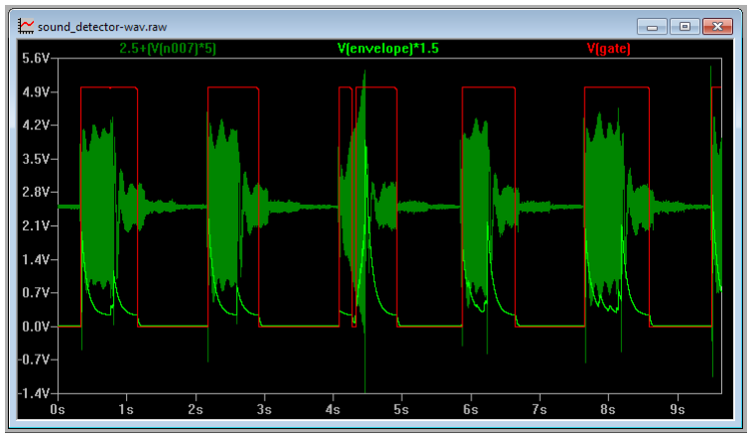
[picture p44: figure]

Este gráfico muestra los voltajes de salida a lo largo del tiempo.

- El trazo verde oscuro es la salida de audio del detector de sonido. El voltaje de audio directamente desde el micrófono se encuentra en esta salida.
- El trazo verde claro es la envolvente. Este voltaje analógico rastrea la amplitud del sonido. Se puede observar que el tercer pulso se vuelve notablemente más fuerte a medida que avanza.
- Finalmente, la línea roja es la salida de la puerta. Esta salida es baja cuando las condiciones son tranquilas y aumenta cuando se detecta sonido.
(B) Y tenemos que determinar el valor base que corresponda con la medida en silencio.
1. Calculamos el ruido medio del periodo de ciclo de transmisión que es de 10 minutos. La formula matemática del calculo del nivel de presión sonora continuo equivalente en dB es:

Donde: Leq = p0 = nivel de presión de referencia
(típicamente 20 µPa) pA =
presión sonora adquirida t1 = tiempo de inicio de la medición t2 = tiempo de finalización de la medición
2. Finalmente para obtener el LAeq basándonos en la
media y no al Leq anterior
que sería lo correcto.
Aplicamos la fórmula que

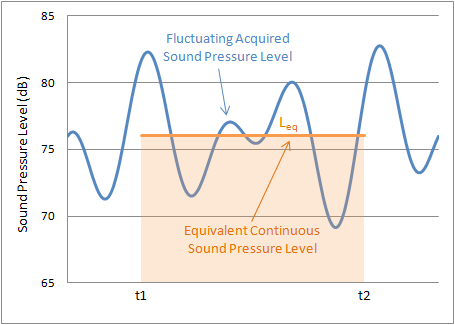
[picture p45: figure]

nos dará una magnitud en decibelios:

### LAeq = Calibración * 20 * log10 ( Ruido Medio / Ruido Base )

### Umbrales de alarmas y avisos

Todas las medidas de ruido son valoradas conforme a los siguientes límites basados en los niveles recomendados por La Organización Mundial de la Salud (OMS) según lo publicado en enero de 2019 bajo el título de “Environmental noise guidelines for the European Region”

- Ruido diurnos en zonas residenciales no superen los 55 decibelios (dB) para evitar molestias y efectos adversos para la salud.
- Para la noche, el límite recomendado es generalmente más bajo, alrededor de 40 dB, para prevenir perturbaciones en el sueño.

Sin embargo el sistema se han ajustado los límites a valores superiores para alinearlos con las regulaciones locales:

Horario | Límite alarma | Límite aviso
De 8h a 24h | 85 dBa | 65 dBa
De 24h a 8 h | 55 dBa | 45 dBa

Se consideran avisos a aquellas mediciones que aunque no superen los límites, están próximos.

Las alarmas están clasificadas según el tipo de medición:
- Ruido medio excedido. Cuando el LAeq ha excedido durante todo el periodo de medición: 10 minutos.
- Ruido mínimo excedido. Cuando esta medición a superado el límite en algún momento.
- Ruido máximo puntual. El sistema registra los tres últimos periodos de 10 minutos. Y si de forma consecutiva se han superado los límites. Se emite esta alarma.

## 4. Análisis de las emisiones acústicas

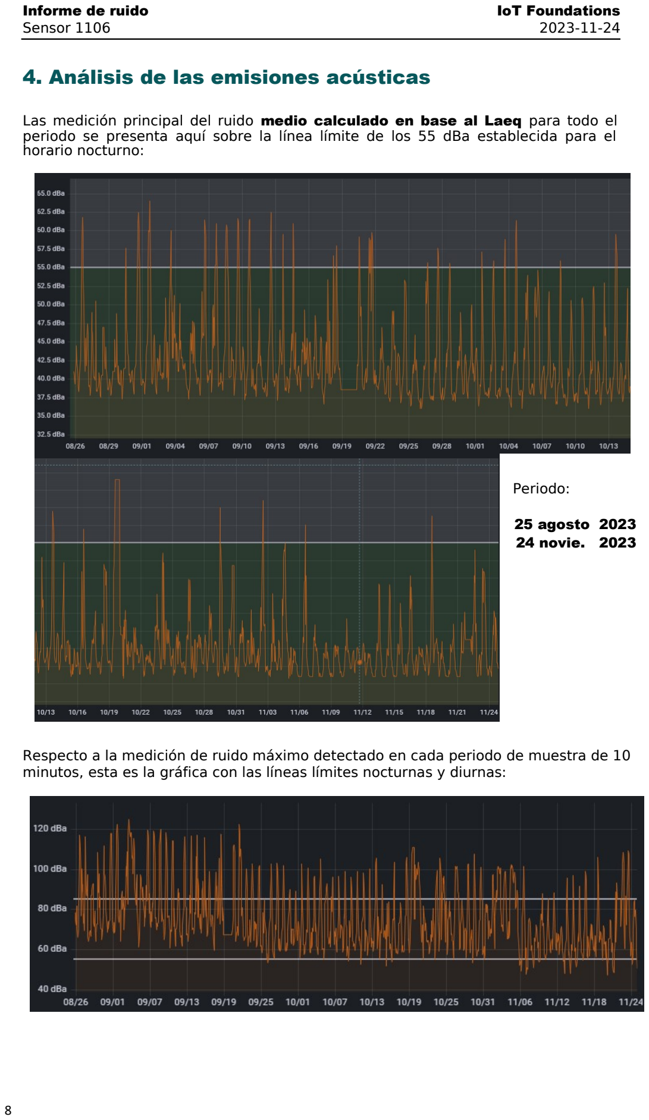
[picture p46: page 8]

Las medición principal del ruido medio calculado en base al Laeq para todo el periodo se presenta aquí sobre la línea límite de los 55 dBa establecida para el horario nocturno:

Periodo:

### 25 agosto 2023 24 novie. 2023

Respecto a la medición de ruido máximo detectado en cada periodo de muestra de 10 minutos, esta es la gráfica con las líneas límites nocturnas y diurnas:

Estas mediciones ha generado las siguientes alarmas y avisos:

Tipo | Alarmas | Avisos
LAeq superado | 24
LAeq próximo | 119
Ruido puntual | | 5490
Total | 143 | 5490

### Análisis comparativo

Tomando como referencia un sensor sin la problemática descrita en las condiciones de este estudio. En este caso el situado el barrio de Canamunt y en concreto, en la calle Pes Formatge número 2 a 5 metros a altura respecto a la calle.

En la gráfica comparativa del nivel de ruido medio (Laeq). Donde el color amarillo corresponde al sensor estudiado. Se aprecian varias diferencias significativas que revelan un mayor y continuado nivel de ruido:

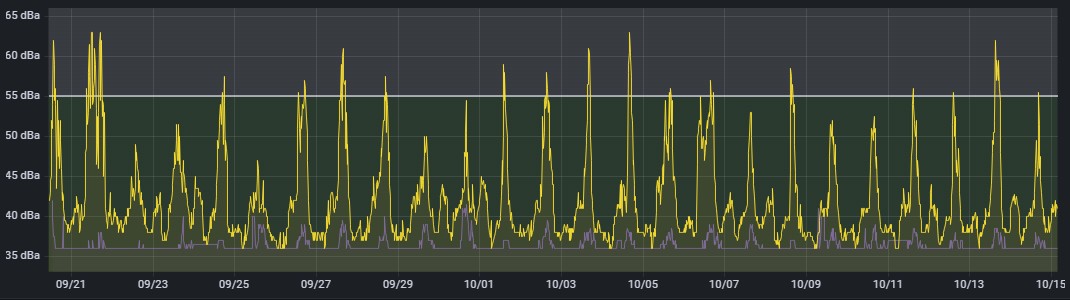
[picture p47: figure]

- La linea base está situada entre uno y dos decibelios más respecto al sensor de referencia.
- Se observa una clara correlación en la curva de incremento de ruido. Pero
con una desviación temporal que marca el inicio de los niveles de ruido
antes, en horas próximas al mediodía.

Si nos centramos en una semana tipo al final de la temporada alta turística como puede ser la última de septiembre.

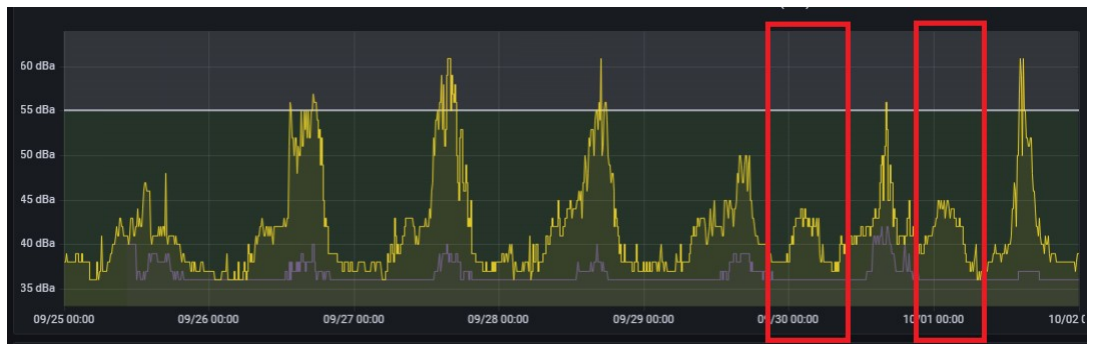
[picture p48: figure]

- Se ha remarcado en rojo los periodos nocturnos donde no hay correlación con el sensor situado en una zona sin locales de ocio nocturno. Es un patrón que se repite durante todo el periodo estudiado.
- Si mostramos el detalle las lecturas de ruido máximo puntual. Se observan algunos valores
sobre el límite
nocturno en la
noche del jueves
al viernes. Pero
en las dos

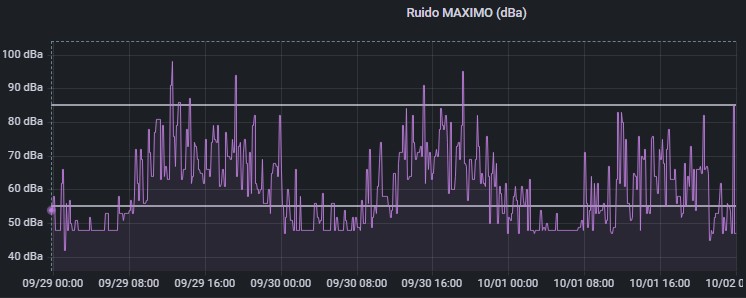
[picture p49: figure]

siguientes, los valores se superan más y durante toda la noche del vienes al sábado.

- Si se presenta un mapa de calor de alarmas de ruido máximo para el periodo comparado anteriormente. Se observa claramente una correlación entre los horarios de apertura de los locales de ocio y las alarmas detectadas cuando se inicia el horario nocturno. También hay que señalar que en las horas anteriores a las 12 de la noche, no se superan los límites establecidos.

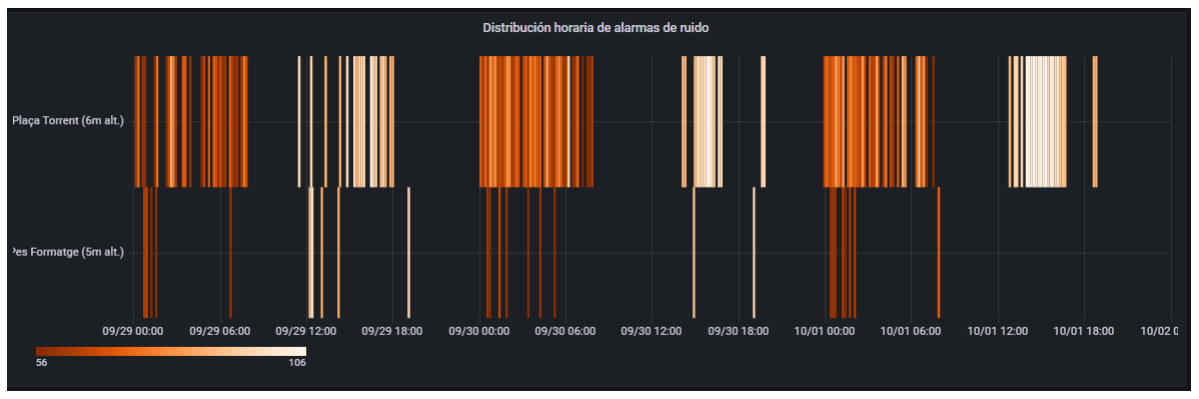
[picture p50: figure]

Este hecho corresponde con los índices de ocupación de los dos locales adyacentes publicados por Google:

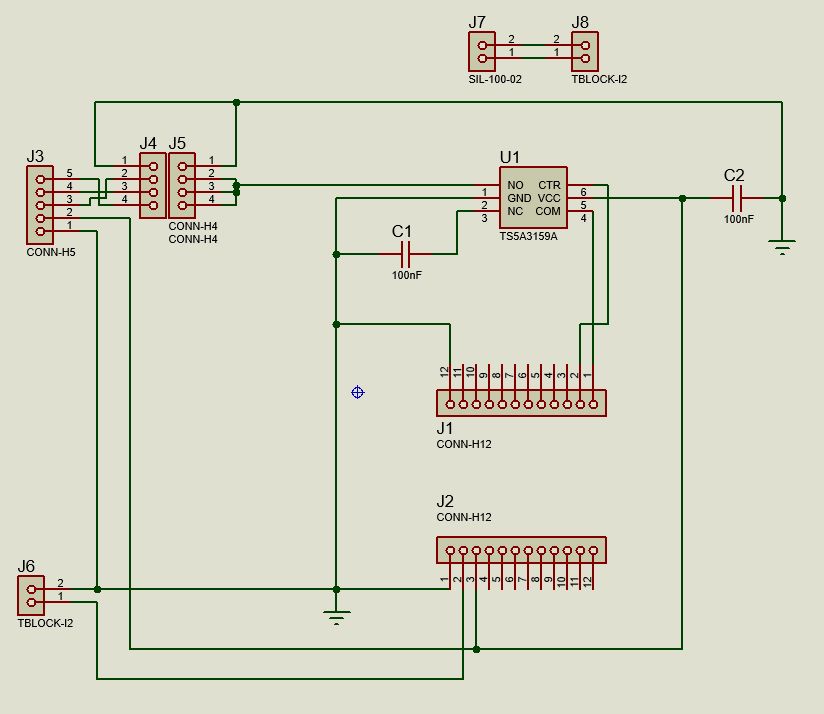
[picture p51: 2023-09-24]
PCB/jaleometro_v1_5_schematic.jpeg

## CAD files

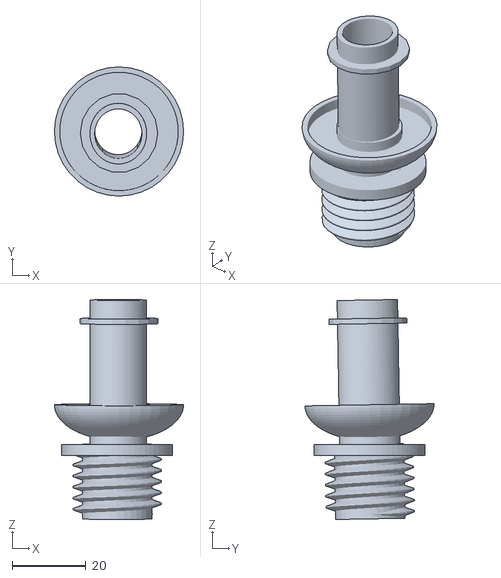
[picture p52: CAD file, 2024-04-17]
3D/Jaleometro_Microphone_Case2.stl
35.0 x 35.0 x 59.6

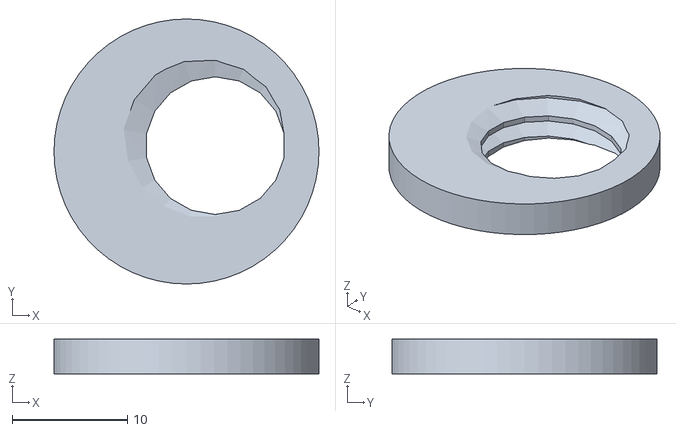
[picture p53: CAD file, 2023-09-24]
3D/Jaleometro_Microphone_Case (cover).stl
23.0 x 23.0 x 3.00

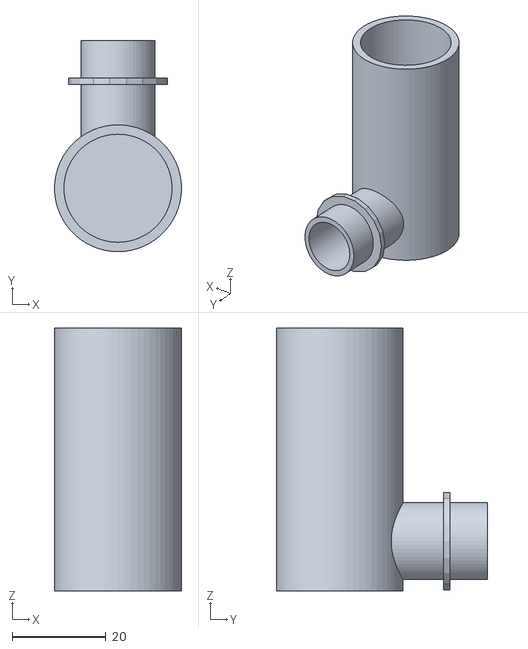
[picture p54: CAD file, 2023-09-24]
3D/Jaleometro_Microphone_Case (body).stl
27.1 x 45.0 x 56.0

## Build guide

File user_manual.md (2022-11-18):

#   Jaleómetro. Manual de instalación y mantenimiento.
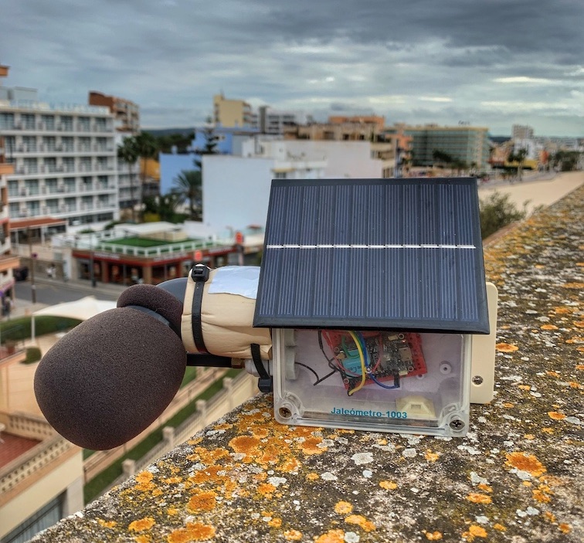
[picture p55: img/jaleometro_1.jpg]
 

Lo más importante es que como hospedador de este dispositivo, estás ayudando a desarrollar una red de Ciencia Ciudadana que captura una información clave para saber objetivamente cómo mejorar la calidad de vida de tu barrio.

Este proyecto ha nacido del movimiento Maker y gracias al apoyo de la [AVV Canamunt](https://es-la.facebook.com/avvcanamunt/).

## ¿Qué es el Jaleómetro?

Jaleométro es un sensor experimental diseñado para monitorizar el ruido ambiental de forma automática utilizando energía solar.

## ¿Para qué sirve el Jaleómetro?

**Sirve para monitorizar el ruido que hay fuera de tu casa**. Es muy importante ser consciente de este valor de nuestro entorno que puede afectar a nuestra salud. 

Por otra parte Registra 24h al día lo que ha pasado y mostrando junto con otros sensores, el ruido que hay en tu barrio. También enviará una alerta si el nivel de ruido supera el valor establecido como molesto. Toda esta información la puedes consultar en la web: http://canamunt.mooo.com:48055/ui

## Qué detecta y como se comunica

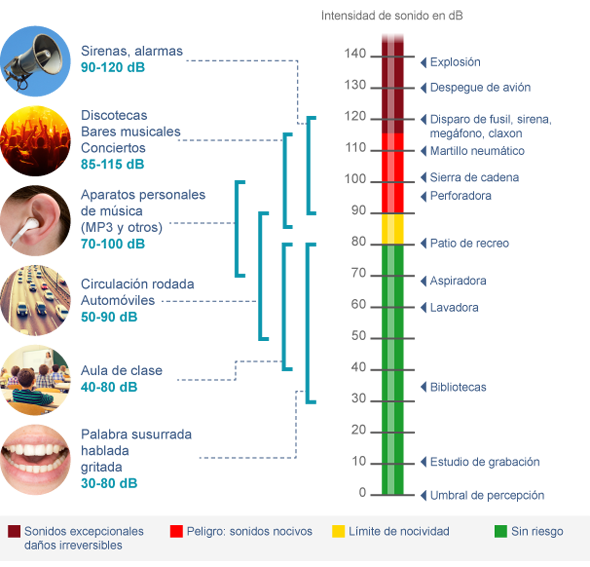
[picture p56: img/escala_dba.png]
 

El dispositivo tiene un micrófono con el que mide una vez cada segundo el nivel de ruido ambiental. Analizando la media, máxima y mínima de los valores durante diez minutos al cabo de los cuales transmitirá esta información a un servidor. 

Para ello utiliza una red de transmisión inalámbrica libre y gratuita desarrollada por la iniciativa [TTN](https://www.thethingsnetwork.org/community/mallorca/). Tanto los datos transmitidos cómo la ubicación exacta del sensor están codificados asegurando tu anonimato.
<br>
<br>
<br>

## Instalación
### ¿Dónde colocar el sensor?
El dispositivo está construido para permanecer en el exterior con el objetivo de medir directamente el ruido ambiental. Por lo tanto busca un lugar en tu balcón o terraza con las siguientes características:

- [ ] **Alejado de fuentes de ruido** permanente como altavoces o máquinas como aires acondicionados, lavadoras, etc...

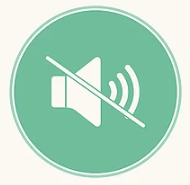
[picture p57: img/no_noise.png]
 

- [ ] **La orientado al Sur es lo mas importante** Aunque puede aguantar unos tres días sin iluminación. Sin la luz del sol acabará apagandose y no servirá de nada.

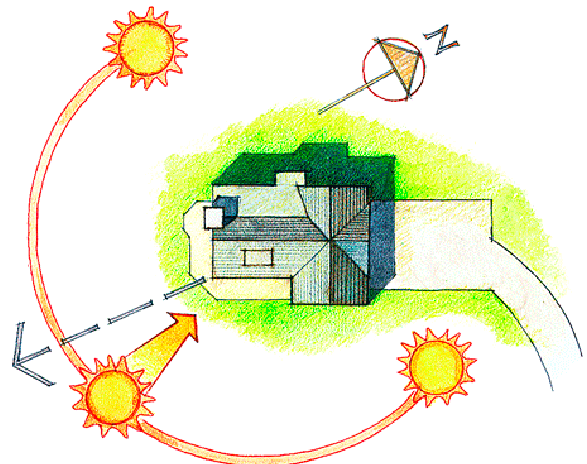
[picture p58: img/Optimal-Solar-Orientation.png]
 

> ¿Cómo saber dónde está el Sur? Puedes utilizar la brújula de tu móvil o esperar a que sean las 12 horas del mediodía para colocar el Jaleómetro de manera que sus paneles miren al sol en ese momento.

- [ ] **Cuidado con las vibraciones**. Si sujetas el sensor a un elemento que puede moverse como una barandilla o mástil. Es conveniente que utilices la pieza de espuma adhesiva entre el sensor y el soporte de metal antes de fijarlo con bridas.

### Recomendaciones y cuidados del sensor
- Intenta mantener limpio el panel solar.
- Estate atenta/o a tu buzón de correo. **Si hay alguna incidencia con tu dispositivo, te enviaremos un correo**
- Subscríbete al canal de Telegram: https://t.me/aa_canamunt para recibir las notificaciones y avisos así como para dar a conocer tus opiniones o sugerencias.

```
Agradecemos sinceramente tu ayuda desinteresada a este proyecto de Ciencia Ciudadana
```

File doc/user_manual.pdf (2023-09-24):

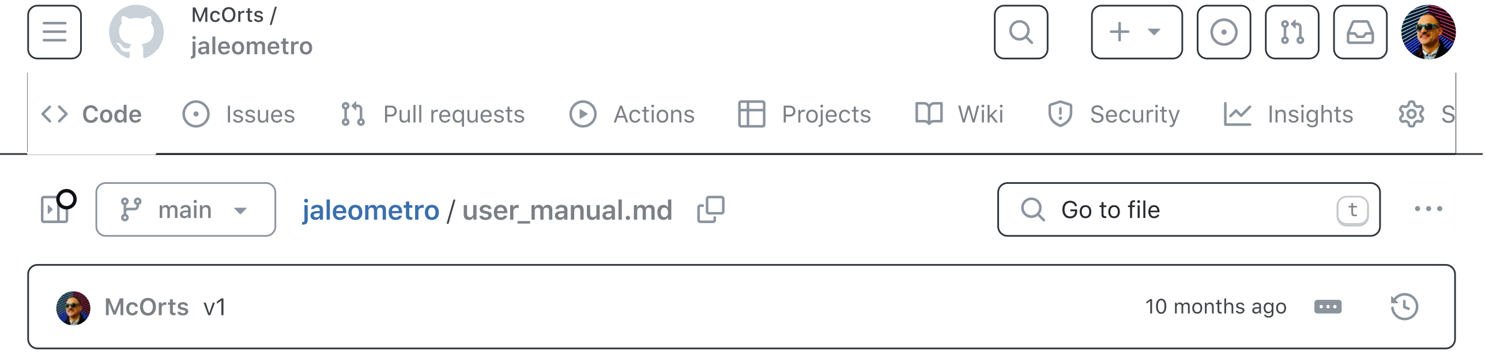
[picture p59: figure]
10 months ago; McOrts / jaleometro; Code; Issues; Pull requests; Actions; Projects; Wiki; Security; Insights; main; jaleometro / user_manual.md; Go to file; McOrts

### 56 lines (32 loc) · 3.36 KB

# Jaleómetro. Manual de instalación y

mantenimiento.

Lo más importante es que como hospedador de este dispositivo, estás ayudando a desarrollar una red de Ciencia Ciudadana que captura una información clave para saber objetivamente cómo mejorar la calidad de vida de tu barrio.

Este proyecto ha nacido del movimiento Maker y gracias al apoyo de la AVV Canamunt. (https://es-la.facebook.com/avvcanamunt/)

## ¿Qué es el Jaleómetro?

Jaleométro es un sensor experimental diseñado para monitorizar el ruido ambiental de forma automática utilizando energía solar.

## ¿Para qué sirve el Jaleómetro?

Sirve para monitorizar el ruido que hay fuera de tu casa. Es muy importante ser consciente de este valor de nuestro entorno que puede afectar a nuestra salud.

Por otra parte Registra 24h al día lo que ha pasado y mostrando junto con otros sensores, el ruido que hay en tu barrio. También enviará una alerta si el nivel de ruido supera el valor establecido como molesto. Toda esta información la puedes consultar en la web: http://canamunt.mooo.com:48055/ui

Preview | Code | Blame | Raw (https://github.com/McOrts/jaleometro/raw/main/user_manual.md)

## Qué detecta y como se comunica

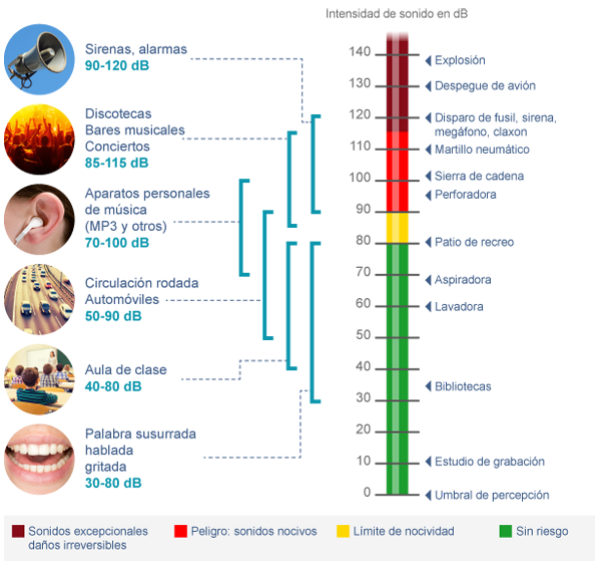
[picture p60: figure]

El dispositivo tiene un micrófono
con el que mide una vez cada
segundo el nivel de ruido
ambiental. Analizando la media, máxima y mínima de los valores durante diez minutos al cabo de los cuales transmitirá esta información a un servidor.

Para ello utiliza una red de transmisión inalámbrica libre y gratuita desarrollada por la iniciativa TTN. (https://www.thethingsnetwork.org/community/mallorca/) Tanto los datos transmitidos cómo la ubicación exacta del sensor están
codificados asegurando tu
anonimato.

## Instalación

### ¿Dónde colocar el sensor?

El dispositivo está construido para permanecer en el exterior con el objetivo de medir directamente el ruido ambiental. Por lo tanto busca un lugar en tu balcón o terraza con las siguientes características:

Alejado de fuentes de ruido permanente como altavoces o máquinas como aires acondicionados, lavadoras, etc...

La orientado al Sur es lo mas importante Aunque puede aguantar unos tres días sin iluminación. Sin la luz del sol acabará apagandose y no servirá de nada.

¿Cómo saber dónde está el Sur? Puedes utilizar la brújula de tu móvil o esperar a que sean las 12 horas del mediodía para colocar el Jaleómetro de manera que sus paneles miren al sol en ese momento.

### Recomendaciones y cuidados del sensor

Intenta mantener limpio el panel solar.
Estate atenta/o a tu buzón de correo. Si hay alguna incidencia con tu dispositivo, te enviaremos un correo
Subscríbete al canal de Telegram: https://t.me/aa_canamunt para recibir las notificaciones y avisos así como para dar a conocer tus opiniones o sugerencias.

Cuidado con las vibraciones. Si sujetas el sensor a un elemento que puede moverse como una barandilla o mástil. Es conveniente que utilices la pieza de espuma adhesiva entre el sensor y el soporte de metal antes de fijarlo con bridas.

Agradecemos sinceramente tu ayuda desinteresada a este proyecto de Ciencia Ciudadana

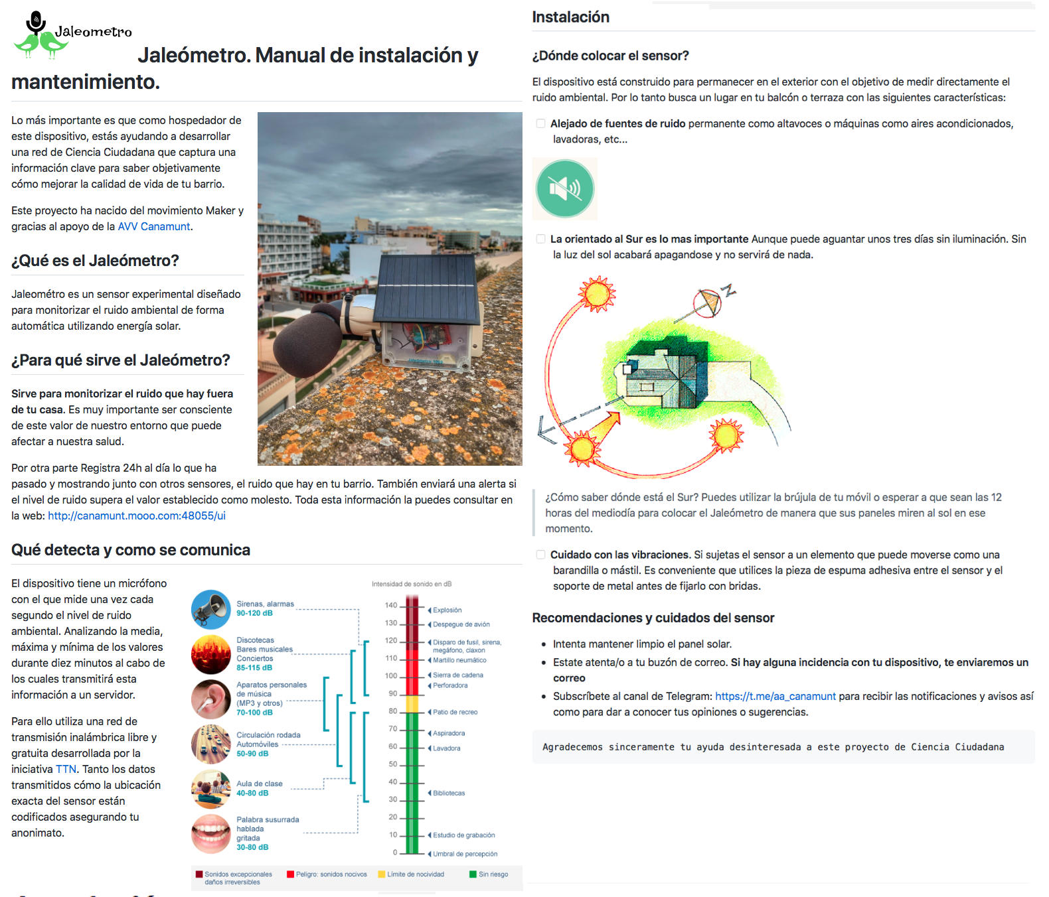
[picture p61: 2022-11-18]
img/Jaleómetro_Manual.png

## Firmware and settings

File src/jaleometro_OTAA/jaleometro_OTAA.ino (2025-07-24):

/**
 *
 * Carlos Orts
 */
#include "LoRaWanMinimal_APP.h"
#include <CayenneLPP.h>//the library needed is https://github.com/ElectronicCats/CayenneLPP with version 1.0.1
#include "Arduino.h"
#include "settings.h"
#include "softSerial.h"

#define Pin_LED_Red GPIO0
#define Pin_LED_Green GPIO4

int loops; // number of readings
unsigned int cycles; // number of read and transmisions cycles.
float icycles; // delta for cycles counter.
float noise_avg; // noise level average
float noise_avg_pre; // noise level average previous
unsigned int noise_peak; // noise peak value
unsigned int noise_min; // noise minimun value
unsigned int noise; // current noise value
unsigned long noise_sum; // noise level addition

///////////////////////////////////////////////////
String outgoingString; // readings in JSON string sent to WiFi module
String incomingString; // readings received from WiFi module
bool wifiConnected; // WiFi module status
int motionVibrations; // Wifi vibration sensor output
softSerial softwareSerial(GPIO1 /*TX pin*/, GPIO2 /*RX pin*/);

///////////////////////////////////////////////////
unsigned long tmp_ini; // Time control reading period
int loops_legal; // number of readings
float noise_avg_legal; // noise level average PMI
float noise_avg_legal_max; // noise level average PMI previous
unsigned int noise_avg_legal_period = 5000; // period of time in miliseconds for legal measurement 
unsigned long noise_sum_legal; // noise level addition
long LegalStart = 0;

float battery;

long CountStart = 0;

CayenneLPP lpp(LORAWAN_APP_DATA_MAX_SIZE);//if use AT mode, don't modify this value or may run dead https://github.com/HelTecAutomation/CubeCell-Arduino/search?q=commissioning.h

bool lorawanConnected; // WiFi module status

///////////////////////////////////////////////////
//Some utilities for going into low power mode
TimerEvent_t sleepTimer;
//Records whether our sleep/low power timer expired
bool sleepTimerExpired;
static void wakeUp()
{
  sleepTimerExpired=true;
}

static void lowPowerSleep(uint32_t sleeptime)
{
  sleepTimerExpired=false;
  TimerInit( &sleepTimer, &wakeUp );
  TimerSetValue( &sleepTimer, sleeptime );
  TimerStart( &sleepTimer );
  //Low power handler also gets interrupted by other timers
  //So wait until our timer had expired
  while (!sleepTimerExpired) lowPowerHandler();
  TimerStop( &sleepTimer );
}

///////////////////////////////////////////////////
void setup() {
	Serial.begin(38400);

  // This disabled (with HIGH) the power of the microphone
  pinMode(Vext, OUTPUT);
  digitalWrite(Vext, HIGH );
  Serial.printf(" | Vext: ");
  Serial.println(digitalRead(Vext));
  delay(500);

  if (moixMode) {
    // initialize digital pin for LED as an output.
    pinMode(Pin_LED_Red, OUTPUT);
    digitalWrite(Pin_LED_Red, LOW);
    pinMode(Pin_LED_Green, OUTPUT);
    digitalWrite(Pin_LED_Green, HIGH);
    Serial.println("MOIX mode activated");
  }

  if (wifiModule){
    softwareSerial.begin(38400);
    wifiConnected = wifiModule;
    motionVibrations = LOW;
  }

  // Sensor identification
  Serial.printf(" | SensorId: ");
  Serial.println(SensorId);

  if (ACTIVE_REGION==LORAMAC_REGION_AU915) {
    //TTN uses sub-band 2 in AU915
    LoRaWAN.setSubBand2();
  }
 
  LoRaWAN.begin(LORAWAN_CLASS, ACTIVE_REGION);
    
  //Enable ADR
  LoRaWAN.setAdaptiveDR(true);

  while (1) {
    Serial.print("Joining... ");
    LoRaWAN.joinOTAA(appEui, appKey, devEui);
    if (!LoRaWAN.isJoined()) {
      //In this example we just loop until we're joined, but you could
      //also go and start doing other things and try again later
      if (wifiModule) {
        Serial.println("JOIN FAILED! proceeding with WiFi conectivity");
        lorawanConnected = false;
        break;
      } else {
        Serial.println("JOIN FAILED! Sleeping for 60 seconds");
        lowPowerSleep(60000);
      }
    } else {
      Serial.println("JOINED");
      lorawanConnected = true;      
      // This enable (with LOW) the power of the microphone
      digitalWrite(Vext, LOW );
      if (LORAWAN_CLASS == CLASS_A) {
        Serial.println("CLASS A Confirmed");
      } else {
        Serial.println("ERROR MOT CLASS A");
      }
      break;
    }
  }

  tmp_ini = millis(); 
  CountStart = millis();  
  noise_avg = LowNoiseLevel;
  noise_avg_legal = LowNoiseLevel;
  noise_avg_pre = LowNoiseLevel;
  noise_avg_legal_max = LowNoiseLevel;
  noise_peak = 0;
  noise_min = 1000; 
  noise_sum = 0;
  noise_sum_legal = 0;
  loops = 0;
  loops_legal = 0;
  cycles = 50;
  icycles = 1;

}

void transmitRecord()
{
  /*
  * set LoraWan_RGB to Active,the RGB active in loraWan
  * RGB red means sending;
  * RGB purple means joined done;
  * RGB blue means RxWindow1;
  * RGB yellow means RxWindow2;
  * RGB green means received done;
  */
   
  // Cayenne
  lpp.reset();
  lpp.addAnalogInput(1,SensorId);
  lpp.addAnalogInput(2,cycles);
  lpp.addAnalogInput(3,battery);
  lpp.addAnalogInput(4,LowNoiseLevel);
  lpp.addLuminosity(1, noise_avg);
  lpp.addLuminosity(2, noise_peak);
  lpp.addLuminosity(3, noise_min);    
  lpp.addLuminosity(4, noise_avg_legal_max); 
  lpp.addLuminosity(5, motionVibrations); 

  //lpp.addGPS(2, latitude, longitude, alt);

  Serial.println("  Transmiting...");
  Serial.print("  lpp data size: ");
  Serial.print(lpp.getSize());
  Serial.println();
  
  // Request ACK only for the 3 firts transmision of a cycle
  bool requestack=cycles<3?true:false;
  
  // if (LoRaWAN.send(1, lpp.getBuffer(), lpp.getSize(), requestack)) {
  if (LoRaWAN.send(lpp.getSize(), lpp.getBuffer(), 2, requestack)) {
    Serial.println("  Send OK");
  } else {
    Serial.println("  Send FAILED");
  }
}

///////////////////////////////////////////////////
void loop() {
  // Noise reading each second
  if (digitalRead(Vext) == 0) {
    noise = analogReadmV(ADC);
  } else {
    digitalWrite(Vext, LOW);
  }

  // ++++++++++++++  Remove outlier ++++++++++++++++
  if (noise > 4500) {
    Serial.print("outlier removed: ");
    Serial.println(noise);
  } else { 
    // Recalculate the LowNoiseLevel
    if (noise < LowNoiseLevel) {
      LowNoiseLevel = noise;
    }
    
    // ++++++++++++++  LAeq based on samples taken every second ++++++++++++++++
    if (millis() - tmp_ini > 1000) {
      noise_sum += noise;
      loops ++;

      Serial.print("Noise: ");
      Serial.print(noise);
      Serial.print(" loop: ");
      Serial.print(loops);
      Serial.print(" cycle: ");
      Serial.print(cycles);
      Serial.print(" loops_legal: ");
      Serial.println(loops_legal); 
      tmp_ini = millis(); 
    }

    // ++++++++++++++  Noise legal calculations ++++++++++++++++
    loops_legal ++;
    noise_sum_legal += noise;
    if (millis() - LegalStart > noise_avg_legal_period) {
      Serial.print(" Legal time: ");
      Serial.println(millis() - LegalStart);
      LegalStart = millis();

      noise_avg_legal = int(noise_sum_legal / loops_legal);
      if (noise_avg_legal > noise_avg_legal_max) {
        noise_avg_legal_max = noise_avg_legal;
        Serial.print("  Noise legal current maximum: ");
        Serial.println(noise_avg_legal_max);
      }

      Serial.print("   (Legal) noise_avg_legal: ");
      Serial.print(noise_avg_legal);
      Serial.print(" noise_avg_legal_max: ");
      Serial.print(noise_avg_legal_max);
      Serial.print(" samples: ");
      Serial.println(loops_legal);

      // LED control of MOIX
      if (moixMode) {
        if (noise_avg_legal > moixRedLevel) {
          digitalWrite(Pin_LED_Green, LOW);
          digitalWrite(Pin_LED_Red, HIGH);
          Serial.println("Red");
        } else {
          digitalWrite(Pin_LED_Red, LOW);
          digitalWrite(Pin_LED_Green, HIGH);
          Serial.println("Green");
        }
      }

      loops_legal = 0;
      noise_sum_legal = 0;
    }

    // ++++++++++++++  Maximun and Minimun detection ++++++++++++++++ 
    if (noise > noise_peak) {
      noise_peak = noise;
      Serial.print("Noise peak: ");
      Serial.println(noise_peak);
    }
    if (noise < noise_min  && loops > 5) { // loops>5 because after the power ON of the micro, the A/D port read low values an the begining 
      noise_min = noise;
      Serial.print("Noise min: ");
      Serial.println(noise_min);
    }
  }

  if (millis() - CountStart > DutyCycle) {
    Serial.print(" DutyCycle time: ");
    Serial.println(millis() - CountStart);
    CountStart = millis();

    // Noise calculations
    noise_avg = int(noise_sum / loops);
    Serial.print("  Noise average: ");
    Serial.println(noise_avg);
    Serial.print("  Noise sum: ");
    Serial.println(noise_sum);
    Serial.print("  Noise min: ");
    Serial.println(noise_min);
    Serial.print("  Samples: ");
    Serial.println(loops);

    // Swith off-on the power of the microphone in order to read the battery
    digitalWrite(Vext, HIGH);
    delay(500);
    battery = getBatteryVoltage();
    Serial.print("  Battery: ");
    Serial.println(battery);
    battery = battery / 100;

    // Cycles control
    if (cycles>99) {
      icycles = -1 ;
    } else if (cycles<1){
      // re-iniciate the LowNoiseLevel to avoid low levels like 0
      LowNoiseLevel = noise_min;
      icycles = +1 ;
    }
    cycles += icycles;

    // WiFi module data sharing
    if (wifiModule) {
      outgoingString = "{";
      outgoingString += "\"analog_in_1\":" + String(SensorId, 2) + ",";
      outgoingString += "\"analog_in_2\":" + String(cycles) + ",";
      outgoingString += "\"analog_in_3\":" + String(battery,2) + ",";
      outgoingString += "\"analog_in_4\":" + String(LowNoiseLevel) + ",";
      outgoingString += "\"luminosity_1\":" + String(noise_avg) + ",";
      outgoingString += "\"luminosity_2\":" + String(noise_peak) + ",";
      outgoingString += "\"luminosity_3\":" + String(noise_min) + ",";
      outgoingString += "\"luminosity_4\":" + String(noise_avg_legal_max);
      outgoingString += "}";
      softwareSerial.println(outgoingString);
      Serial.print("  Sent Serial: ");
      Serial.println(outgoingString);
      delay (500);
      while(softwareSerial.available()) {
        char serialbuffer[64] = {0};
        int i = 0;
        while (softwareSerial.available() && i<63) {
          serialbuffer[i] = (char)softwareSerial.read();
          i++;
        }
        serialbuffer[i] = '\0';
        if(serialbuffer[0]) {
          Serial.print("  Received Serial: ");
          Serial.println(serialbuffer);
          char *commaPos = strchr(serialbuffer, ','); // Find the comma position
          wifiConnected = (strncmp(serialbuffer, "true", 4) == 0); // Check if the start is "true"
          motionVibrations = atoi(commaPos + 1); // Convert the number part to an integer
          Serial.print("  wifiConnected: ");
          Serial.println(wifiConnected);
          Serial.print("  motionVibrations: ");
          Serial.println(motionVibrations);
        }
      }
    }

    if (lorawanConnected) {
      transmitRecord();
    }  
    
    digitalWrite(Vext, LOW);
    Serial.println("  starting microphone....");
    delay(100);
  
    // Low Noise Mode if two Noise Overage are under LowNoiseLevel 
    if (noise_avg < LowNoiseLevel + noiseDiffSleep && noise_avg_pre < LowNoiseLevel + noiseDiffSleep && indoor == false) {
      if (LORAWAN_CLASS == CLASS_A) {
        cycles -= icycles;
        digitalWrite(Vext, HIGH);
        Serial.println("  Switch OFF Microphone");
        Serial.println("  Sleep");
        digitalWrite(Pin_LED_Red, LOW);
        digitalWrite(Pin_LED_Green, LOW);
        delay(400);
        lowPowerSleep(Sleep4NoNoise); 
        digitalWrite(Vext, LOW);
        Serial.println("  Switch ON Microphone");
      }
    } 
    
    noise_peak = 0;
    noise_min = 1000;
    noise_sum = 0;
    loops = 0;
    noise_avg_legal_max = 0;
    noise_avg_pre = noise_avg;

    LegalStart = millis();
  }
}

// Handling downlink data
void downLinkDataHandle(McpsIndication_t *mcpsIndication)
{
  Serial.printf("Received downlink: %s, RXSIZE %d, PORT %d, DATA: ",mcpsIndication->RxSlot?"RXWIN2":"RXWIN1",mcpsIndication->BufferSize,mcpsIndication->Port);
  for(uint8_t i=0;i<mcpsIndication->BufferSize;i++) {
    Serial.printf("%02X",mcpsIndication->Buffer[i]);
    if (mcpsIndication->Port == 1) {
      noiseDiffSleep = mcpsIndication->Buffer[i];
      Serial.print(" | noiseDiffSleep: ");
      Serial.println(noiseDiffSleep);
    }
  }
  Serial.println();
}

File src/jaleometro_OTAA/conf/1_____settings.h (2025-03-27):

// LoRaWAN Configuration

/* OTAA para*/
static uint8_t appEui[] = { 0x00, 0x00, 0x00, 0x00, 0x00, 0x00, 0x00, 0x00 };
static uint8_t devEui[] = { };
static uint8_t appKey[] = { };

uint16_t userChannelsMask[6]={ 0x00FF,0x0000,0x0000,0x0000,0x0000,0x0000 };
static DeviceClass_t lorawanClass = LORAWAN_CLASS;

// Devise location
const float latitude = ;
const float longitude = ;
const int alt = ;

// Other params
float SensorId= 00.00;// Sensor  identifcator number 
const int DutyCycle = 120000; // Transmision and reading period
const int Sleep4NoNoise = 300000; // Sleep period when low noise 
int LowNoiseLevel = 36; // Limit for low noise mode
int noiseDiffSleep = 0; // UPDATED by downlink Port 1. Is the difference in sound level between the minimum and average in a period of sample. 
const bool moixMode = false; // Activate the red & green LED interface and logic
const int moixRedLevel = 41; // Limit for low noise mode
const bool indoor = false; // sleep mode is never activated
const bool wifiModule = false;// WiFi and motion module present

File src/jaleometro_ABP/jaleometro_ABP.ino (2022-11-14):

#include "LoRaWan_APP.h"
#include "Arduino.h"
#include <CayenneLPP.h>//the library is needed https://github.com/ElectronicCats/CayenneLPP
#include "settings.h"

int loops; // number of readings
float cycles; // number of read and transmisions cycles.
float icycles; // delta for cycles counter.
float noise_avg; // noise level average
unsigned int noise_peak; // noise peak value
unsigned int noise_min; // noise minimun value
unsigned int noise; // current noise value
unsigned long noise_sum; // noise level addition
unsigned long tmp_ini; 
unsigned long tmp_pause; 
boolean run_init = true;

/*
 * set LoraWan_RGB to Active,the RGB active in loraWan
 * RGB red means sending;
 * RGB purple means joined done;
 * RGB blue means RxWindow1;
 * RGB yellow means RxWindow2;
 * RGB green means received done;
 */

/*LoraWan channelsmask, default channels 0-7*/ 
uint16_t userChannelsMask[6]={ 0x00FF,0x0000,0x0000,0x0000,0x0000,0x0000 };

/*LoraWan region, select in arduino IDE tools*/
LoRaMacRegion_t loraWanRegion = ACTIVE_REGION;

/*LoraWan Class, Class A and Class C are supported*/
DeviceClass_t  loraWanClass = LORAWAN_CLASS;

/*the application data transmission duty cycle.  value in [ms].*/
uint32_t appTxDutyCycle = ReadDutyCycle;

/*OTAA or ABP*/
bool overTheAirActivation = LORAWAN_NETMODE;

/*ADR enable*/
bool loraWanAdr = LORAWAN_ADR;

/* set LORAWAN_Net_Reserve ON, the node could save the network info to flash, when node reset not need to join again */
bool keepNet = LORAWAN_NET_RESERVE;

/* Indicates if the node is sending confirmed or unconfirmed messages */
bool isTxConfirmed = LORAWAN_UPLINKMODE;

/* Application port */
uint8_t appPort = 2;
/*!
* Number of trials to transmit the frame, if the LoRaMAC layer did not
* receive an acknowledgment. The MAC performs a datarate adaptation,
* according to the LoRaWAN Specification V1.0.2, chapter 18.4, according
* to the following table:
*
* Transmission nb | Data Rate
* ----------------|-----------
* 1 (first)       | DR
* 2               | DR
* 3               | max(DR-1,0)
* 4               | max(DR-1,0)
* 5               | max(DR-2,0)
* 6               | max(DR-2,0)
* 7               | max(DR-3,0)
* 8               | max(DR-3,0)
*
* Note, that if NbTrials is set to 1 or 2, the MAC will not decrease
* the datarate, in case the LoRaMAC layer did not receive an acknowledgment
*/
uint8_t confirmedNbTrials = 4;

/* Prepares the payload of the frame */
static void prepareTxFrame( uint8_t port )
{
  /*appData size is LORAWAN_APP_DATA_MAX_SIZE which is defined in "commissioning.h".
  *appDataSize max value is LORAWAN_APP_DATA_MAX_SIZE.
  *if enabled AT, don't modify LORAWAN_APP_DATA_MAX_SIZE, it may cause system hanging or failure.
  *if disabled AT, LORAWAN_APP_DATA_MAX_SIZE can be modified, the max value is reference to lorawan region and SF.
  *for example, if use REGION_CN470, 
  *the max value for different DR can be found in MaxPayloadOfDatarateCN470 refer to DataratesCN470 and BandwidthsCN470 in "RegionCN470.h".
  */
  if (!run_init) {
    // Cycles control
    if (cycles>99) {
      icycles = -1 ;
    } else if (cycles<1){
      icycles = +1 ;
    }
    cycles += icycles;

    // Noise calculations
    noise_avg = int(noise_sum / loops);
    Serial.print("Noise average: ");
    Serial.println(noise_avg);
    Serial.println(noise_sum);
    Serial.println(loops);
    
    CayenneLPP lpp(LORAWAN_APP_DATA_MAX_SIZE);
    lpp.addAnalogInput(1,SensorId);
    lpp.addAnalogInput(2,cycles);
    lpp.addLuminosity(1, noise_avg);
    lpp.addLuminosity(2, noise_peak);
    lpp.addLuminosity(3, noise_min);    
    lpp.addGPS(2, latitude, longitude, alt);
    lpp.getBuffer(), 
    appDataSize = lpp.getSize();
    memcpy(appData,lpp.getBuffer(),appDataSize);
    Serial.print(appDataSize);
    Serial.println(F(" bytes long LPP packet queued."));    

    noise_peak = 0;
    noise_min = 1000;
    noise_sum = 0;
    loops = 0;
  } else {
    run_init = false;
  }
  
}

void setup() {
  Serial.begin(115200);
 
  tmp_ini = millis(); 
  noise_avg = 0;
  noise_peak = 0;
  noise_min = 1000;  
  noise_sum = 0;
  loops = 0;
  cycles = 1;
  icycles = +1;
 
#if(AT_SUPPORT)
  enableAt();
#endif
  deviceState = DEVICE_STATE_INIT;
  LoRaWAN.ifskipjoin();
  Serial.print("deviceState: "); 
  Serial.println(deviceState); 
}

void loop(){ 

  switch( deviceState )
  {
    case DEVICE_STATE_INIT:
    {
      Serial.println ("Init---------------------"); 
#if(LORAWAN_DEVEUI_AUTO)
      LoRaWAN.generateDeveuiByChipID();
#endif
#if(AT_SUPPORT)
      getDevParam();
#endif
      printDevParam();
      LoRaWAN.init(loraWanClass,loraWanRegion);
      deviceState = DEVICE_STATE_JOIN;
      break;
    }
    case DEVICE_STATE_JOIN:
    {
      Serial.println ("Join--------------------");
      LoRaWAN.join();
      break;
    }
    case DEVICE_STATE_SEND:
    {
      Serial.println ("Send---------------------");
      prepareTxFrame( appPort );
      LoRaWAN.send();
      deviceState = DEVICE_STATE_CYCLE;
      break;
    }
    case DEVICE_STATE_CYCLE:
    {
      Serial.println ("Cycle--------------------");
      // Schedule next packet transmission
      txDutyCycleTime = appTxDutyCycle + randr( 0, APP_TX_DUTYCYCLE_RND );
      LoRaWAN.cycle(txDutyCycleTime);
      deviceState = DEVICE_STATE_SLEEP;

      break;
    }
    case DEVICE_STATE_SLEEP:
    {
      //Serial.println ("Sleep--------------------");

      // Delay to wait transmission ending to avoid interference with the sensor
      if (loops == 0) {      
        tmp_pause = millis();
        while (millis() - tmp_pause < 30000) {
          // wait 30 s
        }
      }

      // Noise reading each second
      noise = analogRead(ADC );
      if (noise > 4500) {
        Serial.println("outlier removed");
      } else {
        if (millis() - tmp_ini > 1000) {
          noise_sum += noise;
          loops ++;
          Serial.print("Noise: ");
          Serial.print(noise);
          Serial.print(" loop: ");
          Serial.print(loops);
          Serial.print(" cycles: ");
          Serial.println(cycles);
          tmp_ini = millis(); 
        }
        if (noise > noise_peak) {
          noise_peak = noise;
          Serial.print("Noise peak: ");
          Serial.println(noise_peak);
        }
        if (noise < noise_min) {
          noise_min = noise;
          Serial.print("Noise min: ");
          Serial.println(noise_min);
        }
      }

      //LoRaWAN.sleep();

      break;
    }
    default:
    {
      Serial.println ("Init---------------------------");      
      deviceState = DEVICE_STATE_INIT;
      break;
    }
  }
}

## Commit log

2022-11-27 sensor tunning
2024-04-17 Create ADAU1401 learning board.pdf
2025-02-02 Mediciones legales, reducción de payload y de DutyCycle
2025-03-24 WiFi & vibration module
    [jaleometro_OTAA.ino, jaleometro_WiFi_module.ino]
